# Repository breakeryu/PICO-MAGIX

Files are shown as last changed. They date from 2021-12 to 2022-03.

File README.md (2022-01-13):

# 1.PICO_MAGIX介绍
什么是PICO_MAGIX呢？
它是一款开源硬件，也是个使用Arduino的开源软件，后续会增加QT应用的一个开源代码仓库。

# 2.Hardware
硬件板卡使用了Altium Designer来设计。工程结构如下：

--hardware文件目录

* * *

--01_SCH        （存放工程的原理图文件）

--02_PCB        （存放工程的PCB文件）

--03_LIB         （存放工程的原理图库和PCB库文件）

--04_DATESHEET      （存放工程使用的数据手册）

--05-DOCUMENT     （存放工程导出的文件和bom等）

--06_PRODUCT        （存放工程的制版信息）

--PICO顶层工程          （使用AD软件打开的工程文件）

# 3.Software

软件使用Arduino IDE来进行编写，主要使用C和C++语言。

工程包括一个单元测试工程和项目发布工程。

目前正在编写单元测试工程。

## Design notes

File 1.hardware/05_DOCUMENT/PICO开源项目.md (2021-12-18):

PICO开源项目

# 一、环境构建

## 1.环境

现在使用PIO很难搞成功。使用arduino原生的IDE可以编译。接下来就用原生的IDE来编辑吧。

## 2.上传

问题中显示了部分上传的方式。

https://community.platformio.org/t/official-platformio-arduino-ide-support-for-the-raspberry-pi-pico-is-now-available/20792/9

## 3.项目开源地址

https://github.com/breakeryu/PICO-MAGIX

# 二、系统设计

## 1.子系统——环境传感器部分

环境传感器部分采用了几个部分：

AHT21B温湿度模块

VL6180X距离模块

st7735显示模块

MQ135气体检测模块

temt6000环境光模块

这样构成了一个环境的检测系统。

### 子系统功能：

该环境监测系统可以进行数据采集，显示。可以设置报警值。

使用QT设计一个上位机，可以使数据可视化，并且可以保存到本地。

## 2.车门/灯状态机系统

这一部分使用状态机测试的code，来模拟一个汽车车门和车灯控制器：

- 车门+车门灯

- 车内头氛围灯（开/关）+ 开关（单刀开关）

- 锁止机构（可以锁各个门，按下之后禁止开门）（单刀开关）

- 车钥匙开门（单刀开关）

- 车门开门（单刀开关）

### 子系统功能：

我们需要8个开关，然后是5个灯。

这样一个车门和灯配合的控制系统，在普通的汽车上面都是常见的。

现在我们使用LED和一些开关按键来模拟这个系统。

## 3.语音识别系统

使用启英泰伦的开源硬件。参考一个开源的灯项目，来集成到我的板卡上面。

# 三、硬件设计

硬件设计开源：在[开源仓库](https://github.com/breakeryu/PICO-MAGIX)中的[1.hardware](https://github.com/breakeryu/PICO-MAGIX/tree/master/1.hardware)部分。

硬件设计使用工具是AD19。原理图和PCB会生成PDF版本。

# 四、软件设计

# 六、项目依赖

使用Arduino平台，集成开发环境使用vscode和pio。

这里是我的主要代码参考文档：https://arduino-pico.readthedocs.io/en/latest/

使用的项目原来的git工程：https://github.com/earlephilhower/arduino-pico

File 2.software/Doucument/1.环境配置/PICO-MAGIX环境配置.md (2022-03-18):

PICO-MAGIX环境配置

# 一、开发环境

## 软件开发环境下载配置

现在使用Arduino IDE来进行开发。具体的使用工具有下面的几个工具：

### 1.Arduino IDE

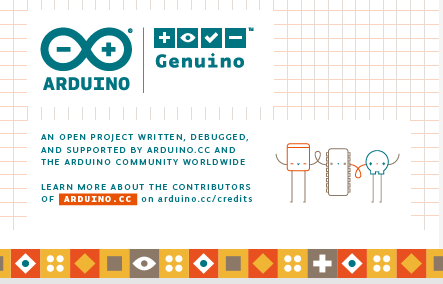
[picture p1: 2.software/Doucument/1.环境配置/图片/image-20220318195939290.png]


下载最新版。不要装在中文路径下面。安装JAVA等依赖。

我们主要使用Arduino IDE来进行工程编译，下载。

### 2.Vscode 

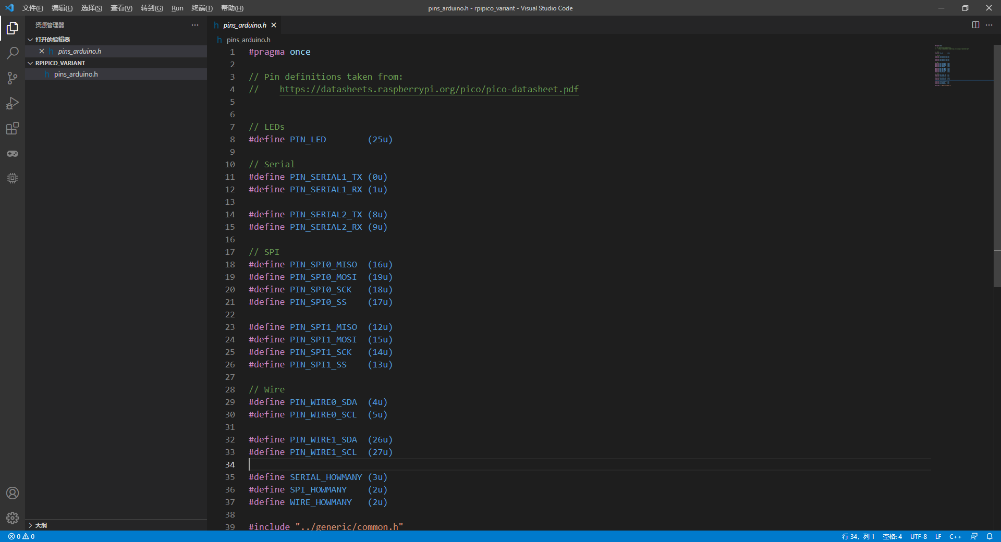
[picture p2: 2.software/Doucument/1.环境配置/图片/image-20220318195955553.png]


下载最新版。下载中文界面、C/C++插件等必要工具。

VScode用来进行编程。

## 环境配置的问题

### 1. vscode的输出中文乱码

如果你使用了VScode插件的版本的Arduino，碰到了编译出错的话，可以看下下面博客的解决办法。

这里为了没有这个错误，建议还是安装Arduino IDE，而不是从其他的地方安装插件。

参考了博客：https://blog.csdn.net/weixin_42225355/article/details/104906950

### 2.头文件包含问题

在VScode中我们只进行编写代码的工作，往往在vs里面会提示找不到相关头文件。

虽然现在没有什么好办法解决这个问题，但是他不影响后面我们编译、运行程序。VS对于我们来讲，他只是一个编写代码的工具。

### 3.文件夹创建方法

在写代码过程中，我们会将一类驱动放在一个文件夹中，使整个工程结构更加的清晰。

这里的说明在ArduinoIDE的环境中，创建相似的文件夹目录。

具体的方法：

- 首先创建文件夹src：这里我使用src文件夹做演示，在src中创建Led文件夹。

- 接着，我们把led.cpp和led.h放在src/Led文件夹中。

  ***注意***

  1.arduino ide使用c++后缀，里面代码可以完全使用c语言，也可以使用c++。但是要注意的是，新建的源文件一定要用cpp后缀。如果使用了c后缀，意思是一个c文件，ide会报错。

  2.文件夹的名字和Led和源文件的名字要有区别，不能完全一样，比如说上面的定义方法：文件夹名字：Led，源文件名：led.cpp。原因目前我还没有深入了解，这个可以给后续的同学研究。

- 在要使用的文件中引用这个文件夹中的头文件。

  使用#include “src/Led/led.h”来应用该文件。

在使用的时候例如下图中的是有工程文件夹，保存了一个src文件夹和其他的源文件：

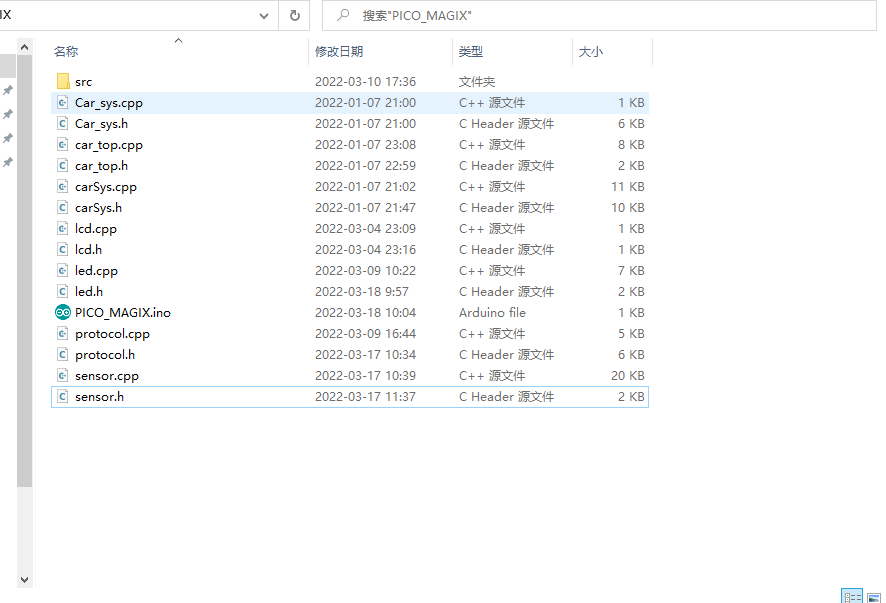
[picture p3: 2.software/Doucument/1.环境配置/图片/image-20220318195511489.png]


src中包含了两个自定义的库文件夹，分别是Modbus和vl6180。

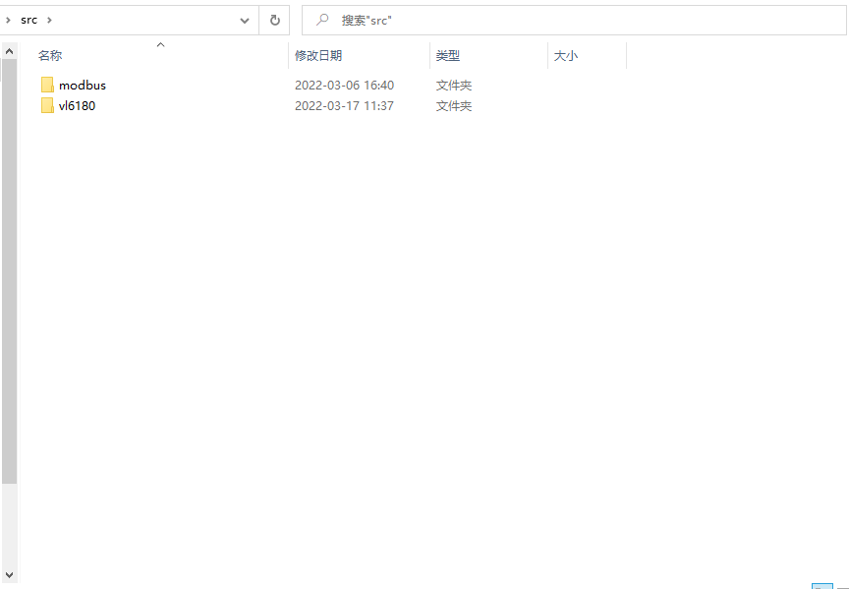
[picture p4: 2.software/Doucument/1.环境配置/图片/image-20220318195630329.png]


在modbus创建的源文件包括下面的部分。

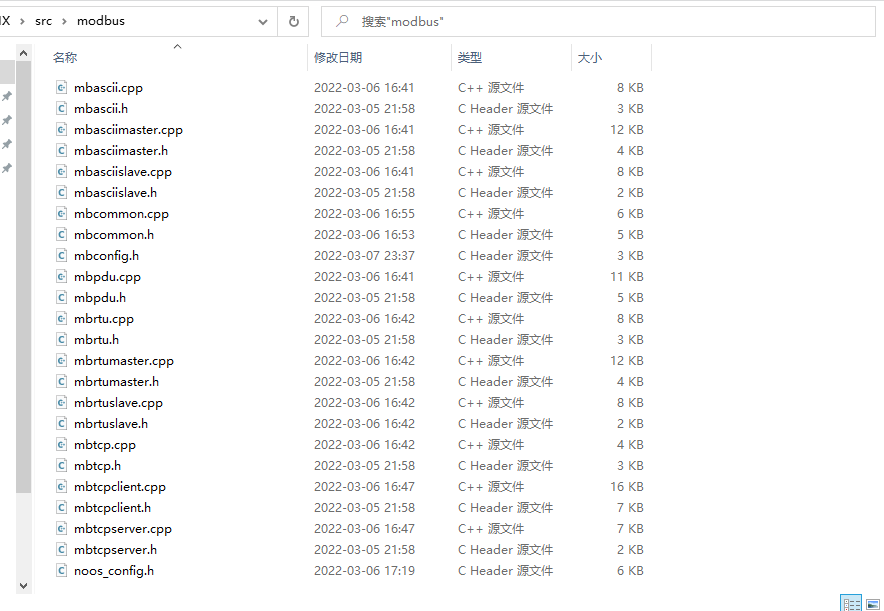
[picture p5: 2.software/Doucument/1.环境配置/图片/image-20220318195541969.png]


在modbus中最好不要再有其他的文件夹，那样会增加自己的工作量。

# 二、开发板环境配置

## Arduino IDE开发板配置

1. 打开 Arduino IDE ， 文件->首选项.

2. 在“附加开发板管理器网址”中新启一行，添加:

    https://github.com/earlephilhower/arduino-pico/releases/download/global/package_rp2040_index.json

3. 点击OK关闭对话框.

4. 点击Tools->Boards->Board Manager in the IDE

5. 搜索 “pico” ，select “Add”。

图文教程点击这里：https://arduino-pico.readthedocs.io/en/latest/install.html#installing-via-arduino-boards-manager

## VS CODE编写文件

1.用VS CODE打开工程文件夹

2.编写代码。

## 引用库文件

在software的文件夹中，lib文件夹中包括了我们使用到的library，这里使用到的库有三个：

> 1. Adafruit_NeoPixel
> 2. AHTxx
> 3. TFT_eSPI

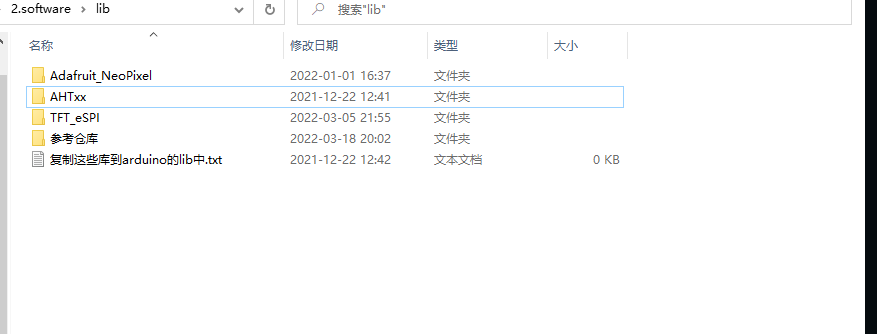
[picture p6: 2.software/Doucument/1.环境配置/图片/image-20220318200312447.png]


将这三个文件夹直接拷贝到arduino的安装路径下的libraries中，例如我的是e盘中的arduino：

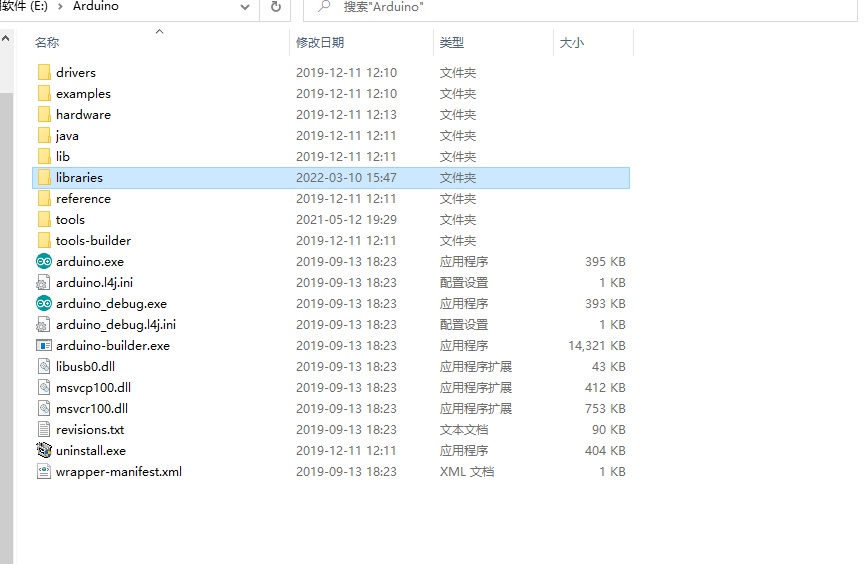
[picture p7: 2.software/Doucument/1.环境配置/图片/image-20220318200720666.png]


### LAST Reference

参考了博客来进行C++的库的编写：

https://www.cnblogs.com/lulipro/p/6090407.html

使用的板卡官方wiki：

https://arduino-pico.readthedocs.io/en/latest/

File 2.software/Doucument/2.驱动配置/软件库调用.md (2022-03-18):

软件库调用

# 1.TFT-eSPI

源仓库地址：https://github.com/Bodmer/TFT_eSPI

我对该仓库进行了修改，适应板子。大家一定要拷贝我给大家的库到你们的arduino路径中，不要直接下载源仓库。

# 2.AHTxx

源仓库地址：https://github.com/enjoyneering/AHTxx

我将这个仓库需要修改成板子能够使用的，接下来放到我的LIB里面。

另外参考的IIC库：

http://enmaking.com/article/ar_os1f1SJq

## 问题：7位的地址位！

以前一直我以为IIC的地址位是8位的，在Arduino的使用中也没有对该问题进行思考。

在今天看AHT20的数据手册和他的参考代码的时候，再回头看这个库，然后发现了这个问题。

对比51单片机和32的历程，这里面的IIC发送和接收都将地址移位加上W/R的位，arduino里面明显没有这个步骤。

在后面的IIC库里面，就有了这一步骤的说明：

**`address: 7bit i2c device address`**

使用Arduino的IIC库的时候，默认已经是将读/写考虑了进来，然后你只需要写入7位的地址位就可以。

# 3.WS2812驱动-Adafruit_NeoPixel

源仓库地址：https://github.com/adafruit/Adafruit_NeoPixel

这里是直接拷贝的源仓库代码。

# 4.MODBUS参考驱动

源仓库地址：木南创智https://github.com/foxclever/Modbus

非常感谢木南团队的贡献，我参考了他们的驱动，很容易就构建出来的自己的MODBUS从机设备。

在我的仓库里面没有下载这个驱动，但是工程中有这里面的驱动源代码。建议大家可以下载该驱动来进行自己的参考设计。

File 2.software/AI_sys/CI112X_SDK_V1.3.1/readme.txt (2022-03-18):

发布版本：CI112X_SDK_V1.3.1

更新内容：

1、更新asr库
（1）、优化解码算力，更新解码库
（2）、增加内存不足（"not enough mem xx"），算力不足提示打印("not enough cpu xx")
（3）、增加默认逐帧配置(针对1102/1103)
（4）、去除冗余打印
2、解决1代串口协议语音关闭后无法通过串口协议打开的bug
3、升级工具更新到版本 V3.4.5

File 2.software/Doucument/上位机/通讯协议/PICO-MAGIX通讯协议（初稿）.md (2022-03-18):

PICO-MAGIX通讯协议（初稿）

# 第一章：综述

PICO_MAGIX通讯协议文件是总括上位机和下位机定义的通讯方式，所有的通讯指令都在本文件中包括。

- 本协议参考MODBUS协议进行编写。

- 本协议软件参考木南协议进行编写。

https://github.com/foxclever/Modbus

- 本协议参考GESHE测控大师软件编写。

http://www.geshe.com/zh-cn/

- 本协议参考“中国电光MODBUS3.0 馈电开关”编写。

# 第二章：通讯协议总括

本章将总括使用的ModBus-RTU通讯协议。

# 各指令对应的地址说明

## 1.读单个线圈01命令（起始地址：00H）

| 线圈起始地址 | 位功能定义 | 事件代码（HEX） |
| :---: | :---: | :---: |
| 00H | 设备停止状态 | —— |
| 01H | 设备运行状态 | —— |
| 02H | 备用 | —— |
| 03H | 备用 | —— |
| 04H | 备用 | —— |
| 05H | 备用 | —— |
| 06H | 备用 | —— |
| 07H | 备用 | —— |
| 08H | 备用 | —— |
| 09H | 备用 | —— |
| 0AH | 备用 | —— |
| 0BH | 备用 | —— |
| 0CH | 备用 | —— |
| 0DH | 备用 | —— |
| 0FH | 备用 | —— |
| 10H | 灯带运行状态（启动：1，停止：0） | |
| 11H | 灯带剧场模式（开启：1，关闭：0） | |
| 12H | 灯带彩虹模式（开启：1，关闭：0） | |
| 13H | 灯带测试模式（开启：1，关闭：0） | |
| | | |
| | | |
| | | |
| | | |
| | | |
| | | |
| | | |
| | | |
| | | |
| | | |

## 2.写单个线圈05命令（起始地址：100H）

| 线圈起始地址 | 位功能定义 | 事件代码（HEX） |
| :---: | :---: | :---: |
| 100H | 灯带运行（启动：1，停止：0） | —— |
| 101H | 灯带剧场打开（开启：1，关闭：0） | —— |
| 102H | 灯带彩虹打开（开启：1，关闭：0） | —— |
| 103H | 灯带测试打开（开启：1，关闭：0） | —— |
| 104H | 读AL6180读写寄存器 | —— |
| 105H | 写AL6180读写寄存器 | —— |
| 106H | 读AL6180结果寄存器 | —— |
| 107H | | —— |
| 108H | | —— |
| 109H | | —— |
| 0AH | | —— |
| 0BH | | —— |
| 0CH | | —— |
| 0DH | | —— |
| 0FH | | —— |
| 10H | | |
| 11H | | |
| 12H | | |
| 13H | | |
| | | |
| | | |
| | | |
| | | |
| | | |
| | | |
| | | |
| | | |
| | | |
| | | |

## 3.读多路寄存器03命令（起始地址：00H）——模拟量

| 寄存器起始地址 | 功能定义 | 系数 |
| :---: | :---: | :--: |
| 00H | 备用 |  ——  |
| 01H | 备用 |  ——  |
| 02H | 备用 |  ——  |
| 03H | 备用 |  ——  |
| 04H | 备用 |  ——  |
| 05H | 备用 |  ——  |
| 06H | 备用 |  ——  |
| 07H | 备用 |  ——  |
| 08H | 备用 |  ——  |
| 09H | 备用 |  ——  |
| 0AH | 系统电压 | 0.01 |
| 0BH | 气体浓度 |  1 |
| 0CH | 光强 |  1 |
| 0DH | 温度 | 0.01 |
| 0EH | 湿度 | 0.01 |
| 0FH | 距离 |  1 |
| 10H | | |
| 11H | | |
| 12H | | |
| 13H | | |
| | | |
| | | |
| | | |
| | | |
| | | |
| | | |
| | | |
| | | |
| | | |
| | | |

## 4.读多路寄存器03命令（起始地址：30H）——定制参数

| 序号 | 寄存器起始地址 | 功能定义 | 备注 |
| ---- | --- | --- | --- |
| 1 | 30H | Model_id | 实际8位无符号，复位后为0xb4 |
| 2 | 31H | Model_Rev_Major | 实际8位无符号，复位后为0x1，值有效范围0~7 |
| 3 | 32H | Model_Rev_Minor | 实际8位无符号，复位后为0x3，值有效范围0~7 |
| 4 | 33H | Module_Rev_Major | 实际8位无符号，复位后为0x1，值有效范围0~7 |
| 5 | 34H | Module_Rev_Minor | 实际8位无符号，复位后为0x2，值有效范围0~7 |
| 6 | 35H | Date_Hi | 实际8位无符号，高4位为年，低4位为月 |
| 7 | 36H | Date_Lo | 实际8位无符号，高4位为日，低4位为脉冲数 |
| 8 | 37H | Id_Time | 实际16位无符号，时间 = 寄存器值 *2 |
| 9 | 38H | Mode_GPIO0 | 实际8位无符号，复位后为0x60 |
| 10 | 39H | Mode_GPIO1 | 实际8位无符号，复位后为0x20 |
| 11 | 3AH | History_Ctrl | 实际8位无符号，复位后为0x0 |
| 12 | 3BH | Interrupt_Config_GPIO | 实际8位无符号，复位后为0x0 |
| 13 | 3CH | Interrupt_Clear | 实际8位无符号，复位后为0x0 |
| 14 | 3DH | Fresh_Out_Of_Reset | 实际8位无符号，复位后为0x1 |
| 15 | 3EH | Grouped_Para_Hold | 实际8位无符号，复位后为0x0 |
| 16 | 3FH | Range_start | 实际8位无符号，复位后为0x0 |
| 17 | 40H | Range_Thresh_High | 实际8位无符号，复位后为0xFF |
| 18 | 41H | Range_Thresh_Low | 实际8位无符号，复位后为0x0 |
| 19 | 42H | Range_InterMeasurement_Period | 实际8位无符号，复位后为0xFF |
| 20 | 43H | Range_Max_ConverGence_Time | 实际8位无符号，复位后为0x31 |
| 21 | 44H | Range_CrossTalk_Compensation_Rate | 实际16位无符号，复位后为0x0 |
| 22 | 45H | Range_CrossTalk_Valid_Height | 实际8位无符号，复位后为0x14 |
| 23 | 46H | Range_Early_ConverGence_Estimate  | 实际16位无符号，复位后为0x0 |
| 24 | 47H | Range_Part_To_Part_Range_Offset | 实际8位无符号，复位后为0xYY |
| 25 | 48H | Range_Ignore_Valid_Height | 实际8位无符号，复位后为0x0 |
| 26 | 49H | Range_Ingore_Threshold | 实际16位无符号，复位后为0x0 |
| 27 | 4AH | Range_Max_Ambient_Level_Mult | 实际8位无符号，复位后为0xA0 |
| 28 | 4BH | Range_Check_Enables | 实际8位无符号，复位后为0x11 |
| 29 | 4CH | Range_Vhv_RecalibRate | 实际8位无符号，复位后为0x0 |
| 30 | 4DH | Range_Vhv_Repeat_Rate | 实际8位无符号，复位后为0x0 |
| 31 | 4EH | Als_Start | 实际8位无符号，复位后为0x0 |
| 32 | 4FH | Als_Thresh_High | 实际16位无符号，复位后为0xFFFF |
| 33 | 50H | Als_Thresh_Low | 实际16位无符号，复位后为0x0 |
| 34 | 51H | Als_InterMeasurement_Period | 实际8位无符号，复位后为0xFF |
| 35 | 52H | Als_Analogue_Gain | 实际8位无符号，复位后为0x06 |
| 36 | 53H | Als_interRation_Period | 实际16位无符号，复位后为0x0 |
| 37 | 54H | Readout_Averaging_Sample_Period | 实际8位无符号，复位后为0x30 |
| 38 | 55H | Firmware_bootup | 实际8位无符号，复位后为0x1 |
| 39 | 56H | Firmaware_Result_Scaler | 实际8位无符号，复位后为0x1 |
| 40 | 57H | I2C_Slave_Device_Adderss | 实际8位无符号，复位后为0x29 |
| 41 | 58H | InterLeaved_Mode_Enable | 实际8位无符号，复位后为0x0 |
| 1 | 59H | Range_Status | 实际8位无符号，复位后为0x01 |
| 2 | 5AH | Als_Status | 实际8位无符号，复位后为0x01 |
| 3 | 5BH | Interrupt_Status_GPIO | 实际8位无符号，复位后为0x00 |
| 4 | 5CH | Als_Value | 实际16位无符号，复位后为0x00 |
| 5 | 5DH | History_Buffer0 | 实际16位无符号，复位后为0x00 |
| 6 | 5EH | History_Buffer1 | 实际16位无符号，复位后为0x00 |
| 7 | 5FH | History_Buffer2 | 实际16位无符号，复位后为0x00 |
| 8 | 60H | History_Buffer3 | 实际16位无符号，复位后为0x00 |
| 9 | 61H | History_Buffer4 | 实际16位无符号，复位后为0x00 |
| 10 | 62H | History_Buffer5 | 实际16位无符号，复位后为0x00 |
| 11 | 63H | History_Buffer6 | 实际16位无符号，复位后为0x00 |
| 12 | 64H | History_Buffer7 | 实际16位无符号，复位后为0x00 |
| 13 | 65H | Range_Value | 实际8位无符号，复位后为0x00 |
| 14 | 66H | Range_Raw | 实际8位无符号，复位后为0x00 |
| 15 | 67H | Range_Rerurn_Rate | 实际16位无符号，复位后为0x00 |
| 16 | 68H | Range_Reference_Rate | 实际16位无符号，复位后为0x00 |
| 17 | 69H | Range_Return_Signal_Count_H | 实际32位无符号，复位后为0x00 |
| 18 | 6AH | Range_Return_Signal_Count_L | 实际32位无符号，复位后为0x00 |
| 19 | 6BH | Range_Reference_Signal_Count_H | 实际32位无符号，复位后为0x00 |
| 20 | 6CH | Range_Reference_Signal_Count_L | 实际32位无符号，复位后为0x00 |
| 21 | 6DH | Range_Return_Amb_Count_H | 实际32位无符号，复位后为0x00 |
| 22 | 6EH | Range_Return_Amb_Count_L | 实际32位无符号，复位后为0x00 |
| 23 | 6FH | Range_Reference_Amb_Count_H | 实际32位无符号，复位后为0x00 |
| 24 | 70H | Range_Reference_Amb_Count_L | 实际32位无符号，复位后为0x00 |
| 25 | 71H | Range_Return_Conv_Time_H | 实际32位无符号，复位后为0x00 |
| 26 | 72H | Range_Return_Conv_Time_L | 实际32位无符号，复位后为0x00 |
| 27 | 73H | Range_Reference_Conv_Time_H | 实际32位无符号，复位后为0x00 |
| 28 | 74H | Range_Reference_Conv_Time_L | 实际32位无符号，复位后为0x00 |

## 5.写单路寄存器06命令、写多路寄存器10命令（起始地址：30H）——定制参数

| 序号 | 寄存器起始地址 | 功能定义 | 备注 |
| ---- | --- | --- | --- |
| 1 | 30H | Model_id | 实际8位无符号，复位后为0xb4 |
| 2 | 31H | Model_Rev_Major | 实际8位无符号，复位后为0x1，值有效范围0~7 |
| 3 | 32H | Model_Rev_Minor | 实际8位无符号，复位后为0x3，值有效范围0~7 |
| 4 | 33H | Module_Rev_Major | 实际8位无符号，复位后为0x1，值有效范围0~7 |
| 5 | 34H | Module_Rev_Minor | 实际8位无符号，复位后为0x2，值有效范围0~7 |
| 6 | 35H | Date_Hi | 实际8位无符号，高4位为年，低4位为月 |
| 7 | 36H | Date_Lo | 实际8位无符号，高4位为日，低4位为脉冲数 |
| 8 | 37H | Id_Time | 实际16位无符号，时间 = 寄存器值 *2 |
| 9 | 38H | Mode_GPIO0 | 实际8位无符号，复位后为0x60 |
| 10 | 39H | Mode_GPIO1 | 实际8位无符号，复位后为0x20 |
| 11 | 3AH | History_Ctrl | 实际8位无符号，复位后为0x0 |
| 12 | 3BH | Interrupt_Config_GPIO | 实际8位无符号，复位后为0x0 |
| 13 | 3CH | Interrupt_Clear | 实际8位无符号，复位后为0x0 |
| 14 | 3DH | Fresh_Out_Of_Reset | 实际8位无符号，复位后为0x1 |
| 15 | 3EH | Grouped_Para_Hold | 实际8位无符号，复位后为0x0 |
| 16 | 3FH | Range_start | 实际8位无符号，复位后为0x0 |
| 17 | 40H | Range_Thresh_High | 实际8位无符号，复位后为0xFF |
| 18 | 41H | Range_Thresh_Low | 实际8位无符号，复位后为0x0 |
| 19 | 42H | Range_InterMeasurement_Period | 实际8位无符号，复位后为0xFF |
| 20 | 43H | Range_Max_ConverGence_Time | 实际8位无符号，复位后为0x31 |
| 21 | 44H | Range_CrossTalk_Compensation_Rate | 实际16位无符号，复位后为0x0 |
| 22 | 45H | Range_CrossTalk_Valid_Height | 实际8位无符号，复位后为0x14 |
| 23 | 46H | Range_Early_ConverGence_Estimate  | 实际16位无符号，复位后为0x0 |
| 24 | 47H | Range_Part_To_Part_Range_Offset | 实际8位无符号，复位后为0xYY |
| 25 | 48H | Range_Ignore_Valid_Height | 实际8位无符号，复位后为0x0 |
| 26 | 49H | Range_Ingore_Threshold | 实际16位无符号，复位后为0x0 |
| 27 | 4AH | Range_Max_Ambient_Level_Mult | 实际8位无符号，复位后为0xA0 |
| 28 | 4BH | Range_Check_Enables | 实际8位无符号，复位后为0x11 |
| 29 | 4CH | Range_Vhv_RecalibRate | 实际8位无符号，复位后为0x0 |
| 30 | 4DH | Range_Vhv_Repeat_Rate | 实际8位无符号，复位后为0x0 |
| 31 | 4EH | Als_Start | 实际8位无符号，复位后为0x0 |
| 32 | 4FH | Als_Thresh_High | 实际16位无符号，复位后为0xFFFF |
| 33 | 50H | Als_Thresh_Low | 实际16位无符号，复位后为0x0 |
| 34 | 51H | Als_InterMeasurement_Period | 实际8位无符号，复位后为0xFF |
| 35 | 52H | Als_Analogue_Gain | 实际8位无符号，复位后为0x06 |
| 36 | 53H | Als_interRation_Period | 实际16位无符号，复位后为0x0 |
| 37 | 54H | Readout_Averaging_Sample_Period | 实际8位无符号，复位后为0x30 |
| 38 | 55H | Firmware_bootup | 实际8位无符号，复位后为0x1 |
| 39 | 56H | Firmaware_Result_Scaler | 实际8位无符号，复位后为0x1 |
| 40 | 57H | I2C_Slave_Device_Adderss | 实际8位无符号，复位后为0x29 |
| 41 | 58H | InterLeaved_Mode_Enable | 实际8位无符号，复位后为0x0 |

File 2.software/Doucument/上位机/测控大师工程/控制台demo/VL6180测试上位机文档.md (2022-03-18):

VL6180测试上位机文档

## 1.寄存器参数读取对照

| 序号 | 寄存器名 | 数据类型 | R/W  | Modbus地址 | 软件变量名 |
| :--: | :---: | :---: | :--: | --- | --- |
|  1 | **IDENTIFICATION__MODEL_ID** | Byte | R/W  | 30H | Model_id |
|  2 | **IDENTIFICATION__MODEL_REV_MAJOR** | Byte | R/W  | 31H | Model_Rev_Major |
|  3 | **IDENTIFICATION__MODEL_REV_MINOR** | Byte | R/W  | 32H | Model_Rev_Minor |
|  4 | **IDENTIFICATION__MODULE_REV_MAJOR** | Byte | R/W  | 33H | Module_Rev_Major |
|  5 | **IDENTIFICATION__MODULE_REV_MINOR** | Byte | R/W  | 34H | Module_Rev_Minor |
|  6 | **IDENTIFICATION__DATE_HI** | Byte | R/W  | 35H | Date_Hi |
|  7 | **IDENTIFICATION__DATE_LO** | Byte | R/W  | 36H | Date_Lo |
|  8 | **IDENTIFICATION__TIME** |  UInt16  | R/W  | 37H | Id_Time |
|  9 | **SYSTEM__MODE_GPIO0** | Byte | R/W  | 38H | Mode_GPIO0 |
|  10  | **SYSTEM__MODE_GPIO1** | Byte | R/W  | 39H | Mode_GPIO1 |
|  11  | **SYSTEM__HISTORY_CTRL** | Byte | R/W  | 3AH | History_Ctrl |
|  12  | **SYSTEM__INTERRUPT_CONFIG_GPIO** | Byte | R/W  | 3BH | Interrupt_Config_GPIO |
|  13  | **SYSTEM__INTERRUPT_CLEAR** | Byte | R/W  | 3CH | Interrupt_Clear |
|  14  | **SYSTEM__FRESH_OUT_OF_RESET** | Byte | R/W  | 3DH | Fresh_Out_Of_Reset |
|  15  | **SYSTEM__GROUPED_PARAMETER_HOLD** | Byte | R/W  | 3EH | Grouped_Para_Hold |
|  16  | **SYSRANGE__START** | Byte | R/W  | 3FH | Range_start |
|  17  | **SYSRANGE__THRESH_HIGH** | Byte | R/W  | 40H | Range_Thresh_High |
|  18  | **SYSRANGE__THRESH_LOW** | Byte | R/W  | 41H | Range_Thresh_Low |
|  19  | **SYSRANGE__INTERMEASUREMENT_PERIOD** | Byte | R/W  | 42H | Range_InterMeasurement_Period |
|  20  | **SYSRANGE__MAX_CONVERGENCE_TIME** | Byte | R/W  | 43H | Range_Max_ConverGence_Time |
|  21  | **SYSRANGE__CROSSTALK_COMPENSATION_RATE** |  UInt16  | R/W  | 44H | Range_CrossTalk_Compensation_Rate |
|  22  | **SYSRANGE__CROSSTALK_VALID_HEIGHT** | Byte | R/W  | 45H | Range_CrossTalk_Valid_Height |
|  23  | **SYSRANGE__EARLY_CONVERGENCE_ESTIMATE**  |  UInt16  | R/W  | 46H | Range_Early_ConverGence_Estimate  |
|  24  |  **SYSRANGE__PART_TO_PART_RANGE_OFFSET**  | Byte | R/W  | 47H | Range_Part_To_Part_Range_Offset |
|  25  |  **SYSRANGE__RANGE_IGNORE_VALID_HEIGHT**  | Byte | R/W  | 48H | Range_Ignore_Valid_Height |
|  26  | **SYSRANGE__RANGE_IGNORE_THRESHOLD** |  UInt16  | R/W  | 49H | Range_Ingore_Threshold |
|  27  | **SYSRANGE__MAX_AMBIENT_LEVEL_MULT** | Byte | R/W  | 4AH | Range_Max_Ambient_Level_Mult |
|  28  | **SYSRANGE__RANGE_CHECK_ENABLES** | Byte | R/W  | 4BH | Range_Check_Enables |
|  29  | **SYSRANGE__VHV_RECALIBRATE** | Byte | R/W  | 4CH | Range_Vhv_RecalibRate |
|  30  | **SYSRANGE__VHV_REPEAT_RATE** | Byte | R/W  | 4DH | Range_Vhv_Repeat_Rate |
|  31  | **SYSALS__START** | Byte | R/W  | 4EH | Als_Start |
|  32  | **SYSALS__THRESH_HIGH** |  UInt16  | R/W  | 4FH | Als_Thresh_High |
|  33  | **SYSALS__THRESH_LOW** |  UInt16  | R/W  | 50H | Als_Thresh_Low |
|  34  | **SYSALS__INTERMEASUREMENT_PERIOD** | Byte | R/W  | 51H | Als_InterMeasurement_Period |
|  35  | **SYSALS__ANALOGUE_GAIN** | Byte | R/W  | 52H | Als_Analogue_Gain |
|  36  | **SYSALS__INTEGRATION_PERIOD** |  UInt16  | R/W  | 53H | Als_interRation_Period |
|  37  | **RESULT__RANGE_STATUS** | Byte |  R | 59H | Range_Status |
|  38  | **RESULT__ALS_STATUS** | Byte |  R | 5AH | Als_Status |
|  39  | **RESULT__INTERRUPT_STATUS_GPIO** | Byte |  R | 5BH | Interrupt_Status_GPIO |
|  40  | **RESULT__ALS_VAL** |  UInt16  |  R | 5CH | Als_Value |
|  41  | **RESULT__HISTORY_BUFFER_0** |  UInt16  |  R | 5DH | History_Buffer0 |
|  42  | **RESULT__HISTORY_BUFFER_1** |  UInt16  |  R | 5EH | History_Buffer1 |
|  43  | **RESULT__HISTORY_BUFFER_2** |  UInt16  |  R | 5FH | History_Buffer2 |
|  44  | **RESULT__HISTORY_BUFFER_3** |  UInt16  |  R | 60H | History_Buffer3 |
|  45  | **RESULT__HISTORY_BUFFER_4** |  UInt16  |  R | 61H | History_Buffer4 |
|  46  | **RESULT__HISTORY_BUFFER_5** |  UInt16  |  R | 62H | History_Buffer5 |
|  47  | **RESULT__HISTORY_BUFFER_6** |  UInt16  |  R | 63H | History_Buffer6 |
|  48  | **RESULT__HISTORY_BUFFER_7** |  UInt16  |  R | 64H | History_Buffer7 |
|  49  | **RESULT__RANGE_VAL** | Byte |  R | 65H | Range_Value |
|  50  | **RESULT__RANGE_RAW** | Byte |  R | 66H | Range_Raw |
|  51  | **RESULT__RANGE_RETURN_RATE** |  UInt16  |  R | 67H | Range_Rerurn_Rate |
|  52  | **RESULT__RANGE_REFERENCE_RATE** |  UInt16  |  R | 68H | Range_Reference_Rate |
|  53  | **RESULT__RANGE_RETURN_SIGNAL_COUNT** |  UInt32  |  R | 69H\|6AH | Range_Return_Signal_Count |
|  54  | **RESULT__RANGE_REFERENCE_SIGNAL_COUNT**  |  UInt32  |  R | 6BH\|6CH | Range_Reference_Signal_Count |
|  55  | **RESULT__RANGE_RETURN_AMB_COUNT** |  UInt32  |  R | 6DH\|6EH | Range_Return_Amb_Count |
|  56  | **RESULT__RANGE_REFERENCE_AMB_COUNT** |  UInt32  |  R | 6FH\|70H | Range_Reference_Amb_Count |
|  57  | **RESULT__RANGE_RETURN_CONV_TIME** |  UInt32  |  R | 71H\|72H | Range_Return_Conv_Time |
|  58  | **RESULT__RANGE_REFERENCE_CONV_TIME** |  UInt32  |  R | 73H\|74H | Range_Reference_Conv_Time |
|  59  | **READOUT__AVERAGING_SAMPLE_PERIOD** | Byte | R/W  | 54H | Readout_Averaging_Sample_Period |
|  60  | **FIRMWARE__BOOTUP** | Byte | R/W  | 55H | Firmware_bootup |
|  61  | **FIRMWARE__RESULT_SCALER** | Byte | R/W  | 56H | Firmaware_Result_Scaler |
|  62  | **I2C_SLAVE__DEVICE_ADDRESS** | Byte | R/W  | 57H | I2C_Slave_Device_Adderss |
|  63  | **INTERLEAVED_MODE__ENABLE** | Byte | R/W  | 58H | InterLeaved_Mode_Enable |

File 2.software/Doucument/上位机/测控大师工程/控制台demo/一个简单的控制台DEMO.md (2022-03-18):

一个简单的控制台DEMO

# 一、DEMO说明

我们从这个教程中能够练习以下几个格西测控大师的使用方法：

1. 简单控件使用
2. 事件脚本的编写
3. 自定义序列命令
4. 串口设备的使用

# 二、开始吧

## 1.创建一个画面

在画面中，使用了自定义的画布，使用了按键和开关控件。

## 2.创建一个设备和接口

这里的命名为默认名字,串口。

# 三、在脚本中执行步骤的几种方式

## 1.使用步骤的ID名

`Context.StartStep("82BCBA44-AD16-4214-BA0F-AD6D7E3BFC9A");`

## 2.使用步骤所处的序列位置

`Context.StartStep("控制台测试序列/写LED系统状态1");`

## 3.使用变量

`Context.StartStep(Context.Variants["步骤名/LED写1"].ToString());`

# 四、数据绑定

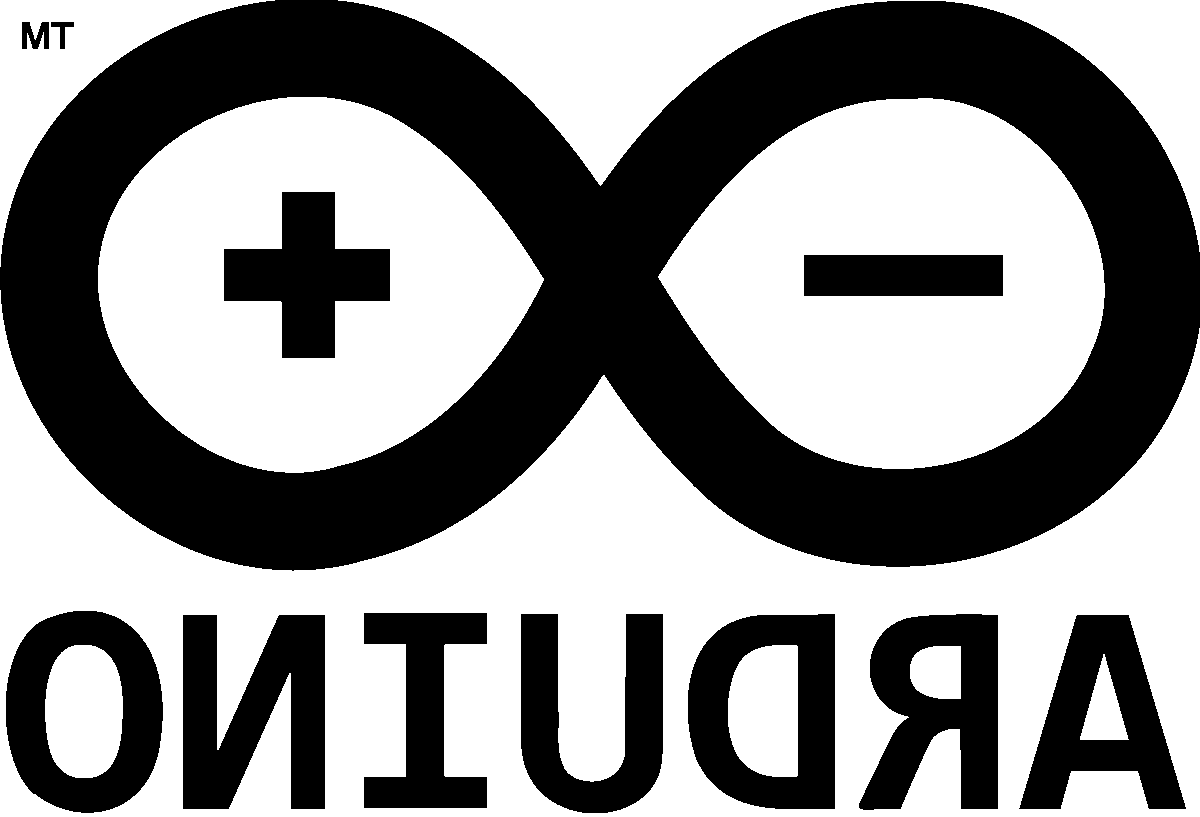
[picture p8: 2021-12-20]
1.hardware/05_DOCUMENT/arduino.bmp

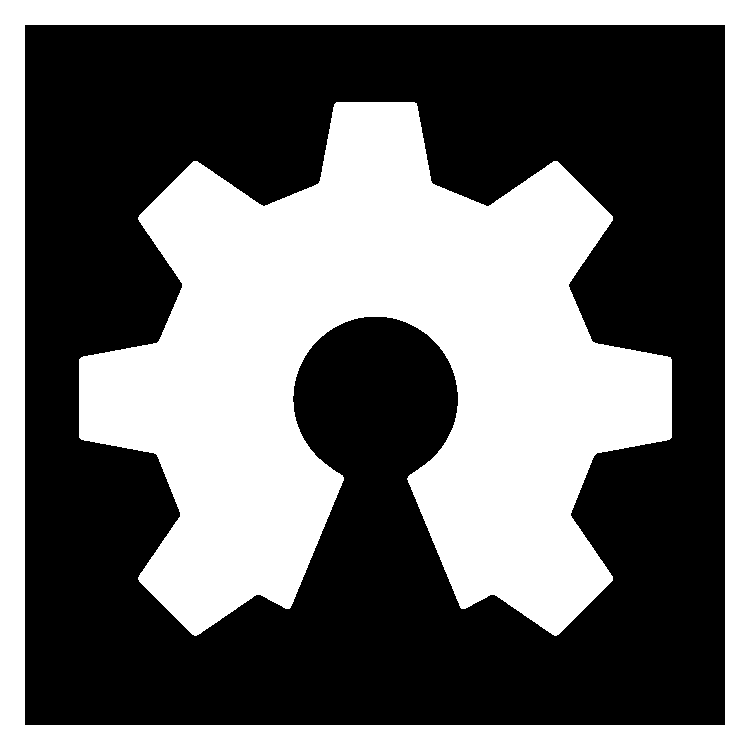
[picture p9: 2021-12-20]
1.hardware/05_DOCUMENT/opensource.bmp

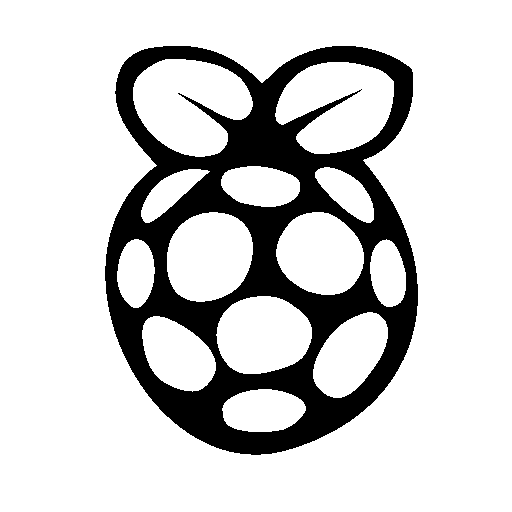
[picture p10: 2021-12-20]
1.hardware/05_DOCUMENT/PI.bmp

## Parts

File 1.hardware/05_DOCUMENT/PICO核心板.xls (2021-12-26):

Comment | Description | Designator | Footprint | LibRef | Quantity
TSA343G00-250J2 |  | BOOTSEL1, RESET1 | SW-SMD_4P-L6.2-W6.3-P4.00-LS9.4 | TSA343G00-250J2 | 2
T_Cap_0603_0.1uF_25V_X5R | 贴片电容 | C1, C5, C21, C23, C24, C27, C28, C30, C32, C33, C34, C35, C36, C37, C38, C39, C40, C41, C42 | 0402_C | T_Cap_0603_0.1uF_25V_X5R | 19
T_Cap_1206_47uF_10V_X5R | 贴片电容 | C2 | 0402_C | T_Cap_1206_47uF_10V_X5R | 1
T_Cap_1206_47uF_10V_X5R | 贴片电容 | C3 | 1206_C | T_Cap_1206_47uF_10V_X5R | 1
T_Cap_0603_10uF_16V_X5R | 贴片电容 | C4, C20, C22 | 0402_C | T_Cap_0603_10uF_16V_X5R | 3
4.7nF |  | C6 | 0402_C | Cap | 1
T_Cap_0603_10nF_50V_X7R | 贴片电容 | C7 | 0402_C | T_Cap_0603_10nF_50V_X7R | 1
39pF |  | C8 | 0402_C | Cap | 1
0.1u |  | C9, C10, C12, C13, C14, C15, C16, C17, C18 | 0402_C | 0.1u | 9
1u |  | C11, C19 | 0402_C | 0.1u | 2
15p |  | C25, C26 | 0402_C | 15p | 2
10n |  | C29 | 0402_C | 10n | 1
1n |  | C31 | 0402_C | 1n | 1
spker |  | C43 | XH2.54A-2 | SPK | 1
3.5*1.3 | 低压电源接口 | CON1 | DC-IN-TH_DC-005-5A-2.5 | P-DC | 1
T_SS34 | 肖特基二极管 | D1 | SMA_L4.3-W2.6-LS5.2-RD | T_SS34 | 1
T_LED_Red_0805 | 红色LED灯 | D2, D3, D4 | 0603_LED | T_LED_Red_0805 | 3
1N4007W |  | D5 | SMA_L4.3-W2.6-LS5.2-RD | 1N4007W | 1
WS2812 |  | D6, D7, D8, D9, D10, D11, D12, D13, D14, D15, D16, D17, D18, D19, D20, D21 | LED-SMD_4P-L3.5-W3.5-TL_WS2812B | WS2812 | 16
st7735 |  | D22 | HDR1X8 | st7735 | 1
T_LED_Red_0805 | 红色LED灯 | D23, D24, D25, D26, D27 | LED-TH_L5.0-W2.7-FD | T_LED_Red_0805 | 5
16V 2A |  | F1 | 1206_FUSE | Fuse | 1
HDR-F-2.54_1x3 |  | H1, H2 | XH2.54A-3 | HDR-F-2.54_1x3 | 2
TSA343G00-250J2 |  | key1, key2, key3, key4, key5, key6, key7, key8 | SW-TH_DEALON_MS-12D19-G2 | TSA343G00-250J2 | 8
6.8uH |  | L1 | IND-SMD_L5.8-W5.2 | Inductor | 1
RGB-3528 | 三基色LED | LED1, LED2, LED3 | LED-TH_4P-BD6.9-P1.27-R | LED-RGB-3528 | 3
咪头 |  | m1 | MIC-TH_BD6.0-P1.90-D0.4-L-RD | mic | 1
Header 2H | Header, 2-Pin, Right Angle | P1 | XH2.54A-2 | Header 2H | 1
T_Res_0603_10k_1%_1/10W | 贴片电阻 | R1, R4, R5 | 0402_R | T_Res_0603_10k_1%_1/10W | 3
49.9k |  | R2 | 0402_R | Res | 1
1.91k |  | R3 | 0402_R | Res | 1
T_Res_0603_4.3k_5%_1/10W | 贴片电阻 | R6, R27, R28, R29, R30, R31, R32, R33, R34, R35, R36, R37, R38, R39 | 0402_R | T_Res_0603_4.3k_5%_1/10W | 14
27 |  | R7, R8 | 0402_R | 27 | 2
DNF（不装） |  | R9 | 0402_R | DNF（不装） | 1
1k |  | R10, R11, R12, R13, R17, R18, R19, R21, R22 | 0402_R | 1k | 9
10k |  | R14, R20 | 0402_R | 1k | 2
200k |  | R15 | 0402_R | 200k | 1
100k |  | R16 | 0402_R | 100k | 1
100r |  | R23, R25, R26 | 0402_R | 100k | 3
4.7k |  | R24 | 0402_R | 100k | 1
W25Q16JVSSIQ |  | ROM1 | SOIC8-208mil | W25Q16JVSSIQ | 1
SS-12F23 | 1路波动开关 | S1, S2 | SW-TH_MT-0-103-A101-M200-RS | SSW-1P | 2
PICO |  | U1 | LQFN-56_L7.0-W7.0-P0.4-EP | PICO_CORE | 1
TPS54331DR | TI, 3A, 3.5-28V, Buck | U2 | SOIC8E | TPS54331 | 1
T_AMS1117-3.3V | 电源芯片 | U3 | SOT223 | T_AMS1117-3.3V | 1
CH340E |  | U4 | MSOP-10_L3.0-W3.0-P0.50-LS5.0-BL | CH340E | 1
气体传感器 |  | U5 | XH2.54A-4 | MQ135 | 1
AHT21B |  | U6 | XH2.54A-4 | AHT21B | 1
VL6180X |  | U7 | XH2.54A-4 | VL6180X | 1
TEMT6000 |  | U8 | XH2.54A-3 | TEMT6000 | 1
CI-C22GS02S |  | U9 | SMD-17_L20.0-W1.80-CI-C22GS02S | CI-C22GS02S | 1
TYPEC-302-BRP16SC08 |  | USB1 | USB-C-SMD_TYPEC-302-BRP16SC08 | TYPEC-302-BRP16SC08 | 1
MICROUSB FEMALE |  | USB2 | USB-B/S_A | MICROUSB FEMALE | 1
12MHz |  | X1 | OSC 3225-4P | 12MHz | 1

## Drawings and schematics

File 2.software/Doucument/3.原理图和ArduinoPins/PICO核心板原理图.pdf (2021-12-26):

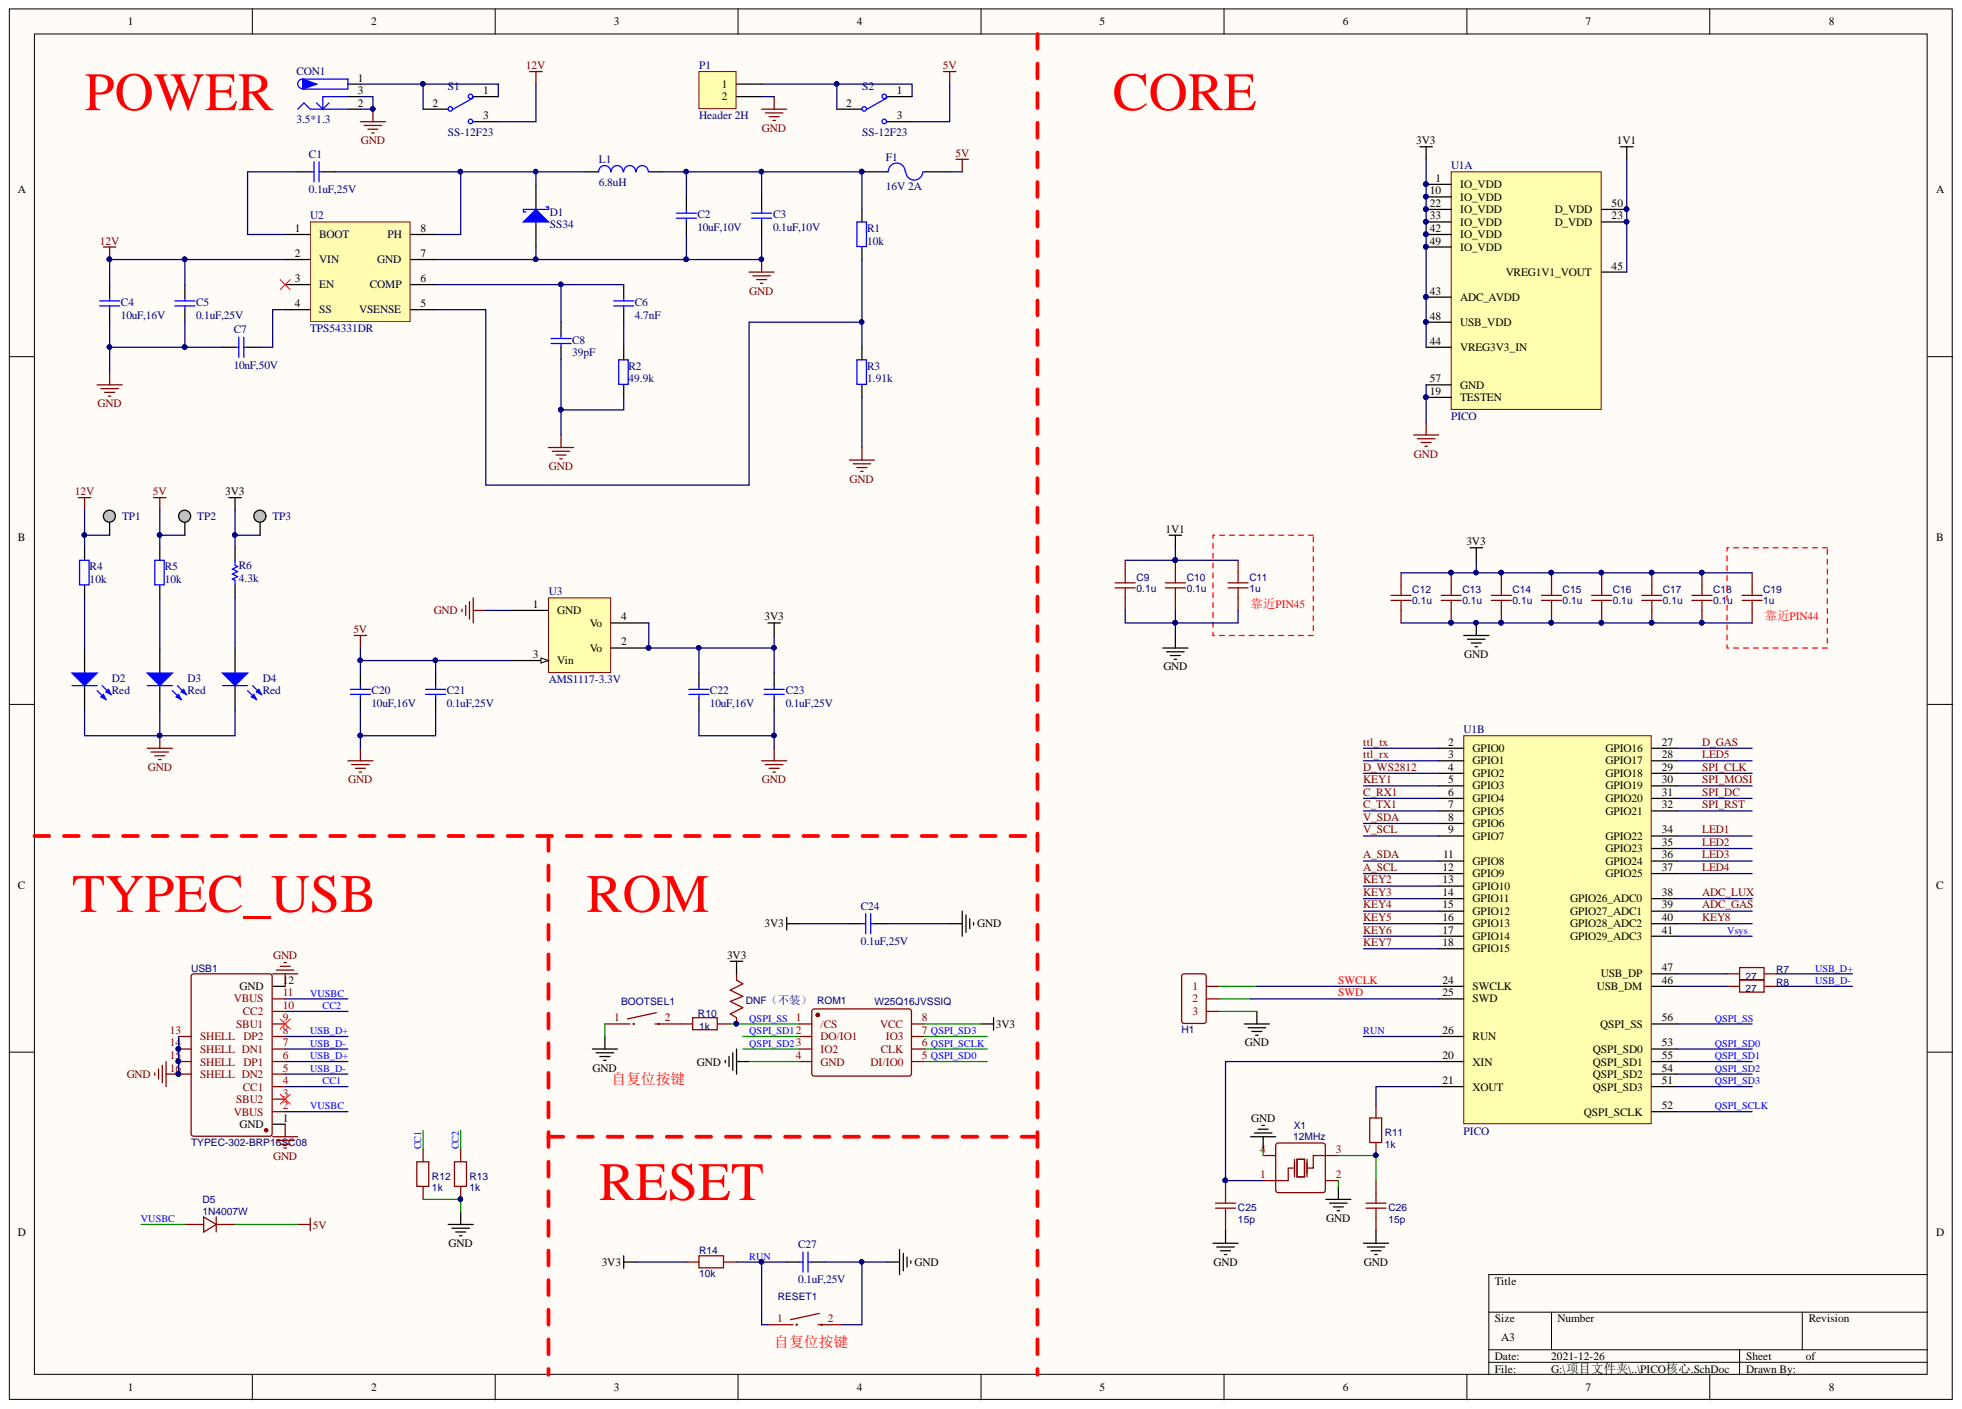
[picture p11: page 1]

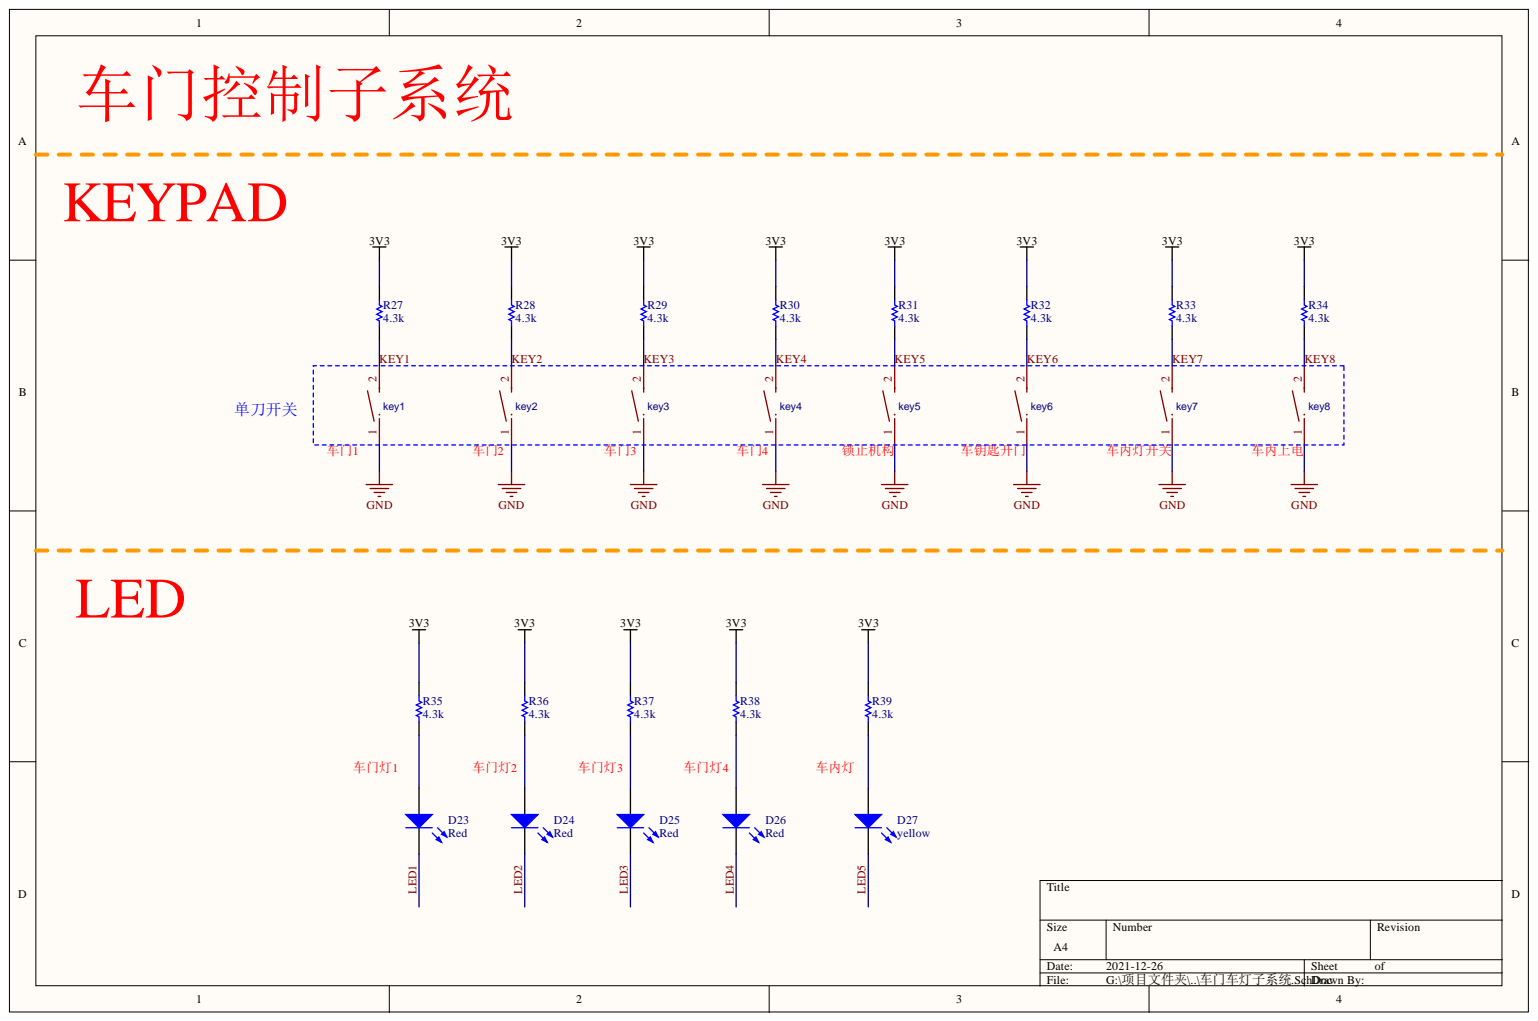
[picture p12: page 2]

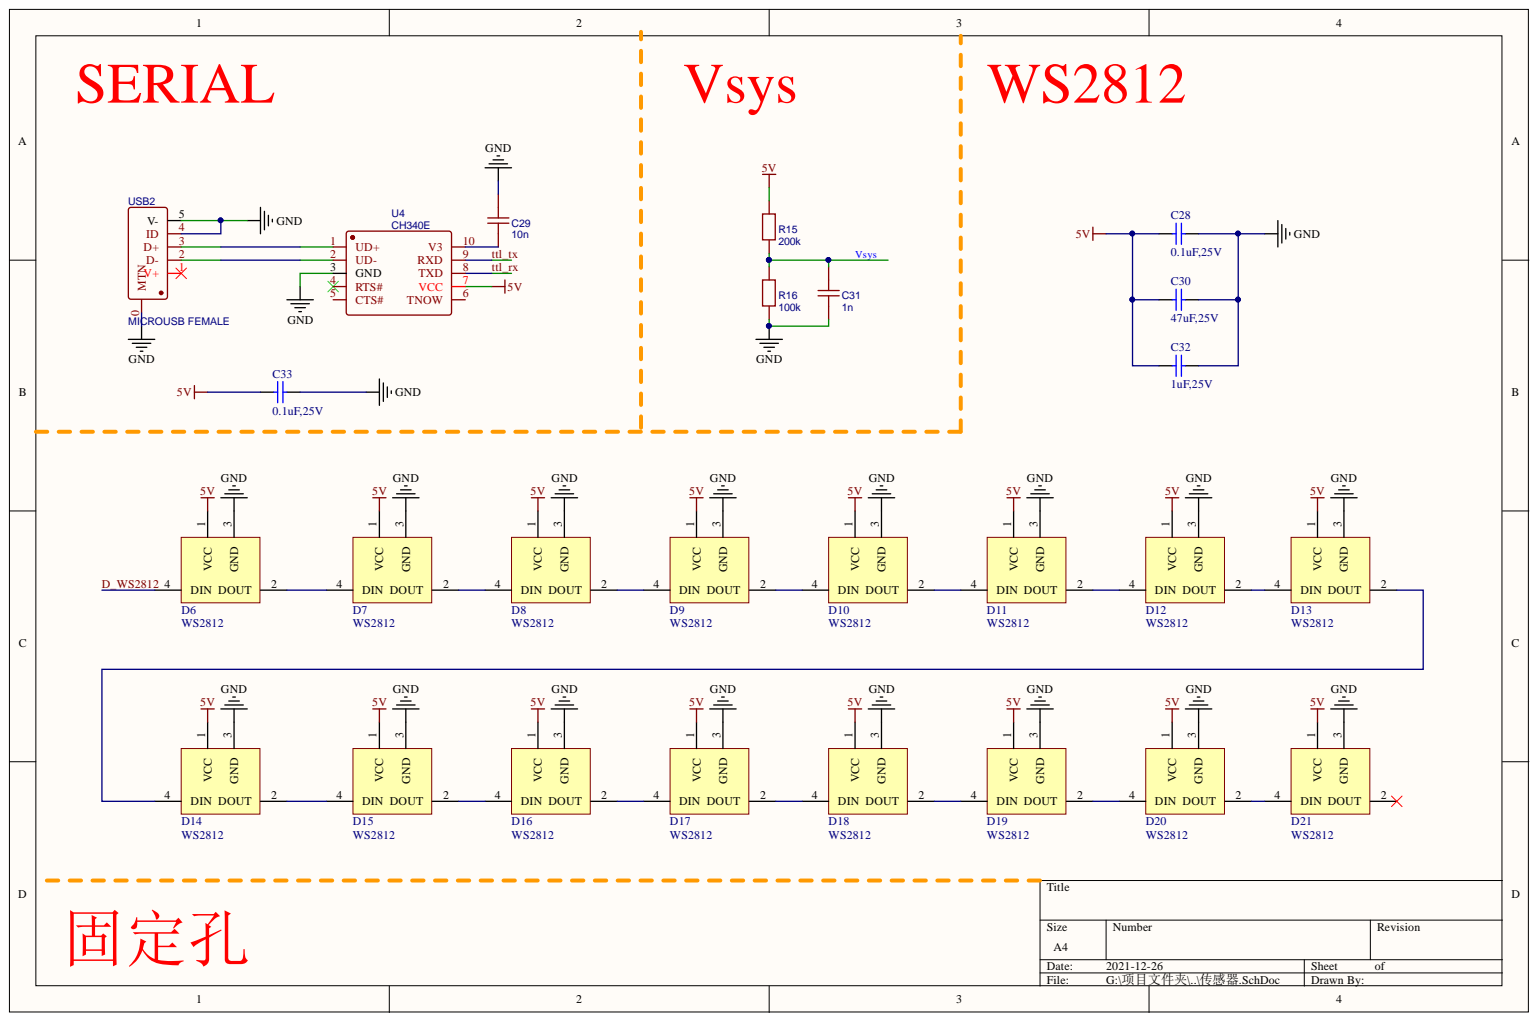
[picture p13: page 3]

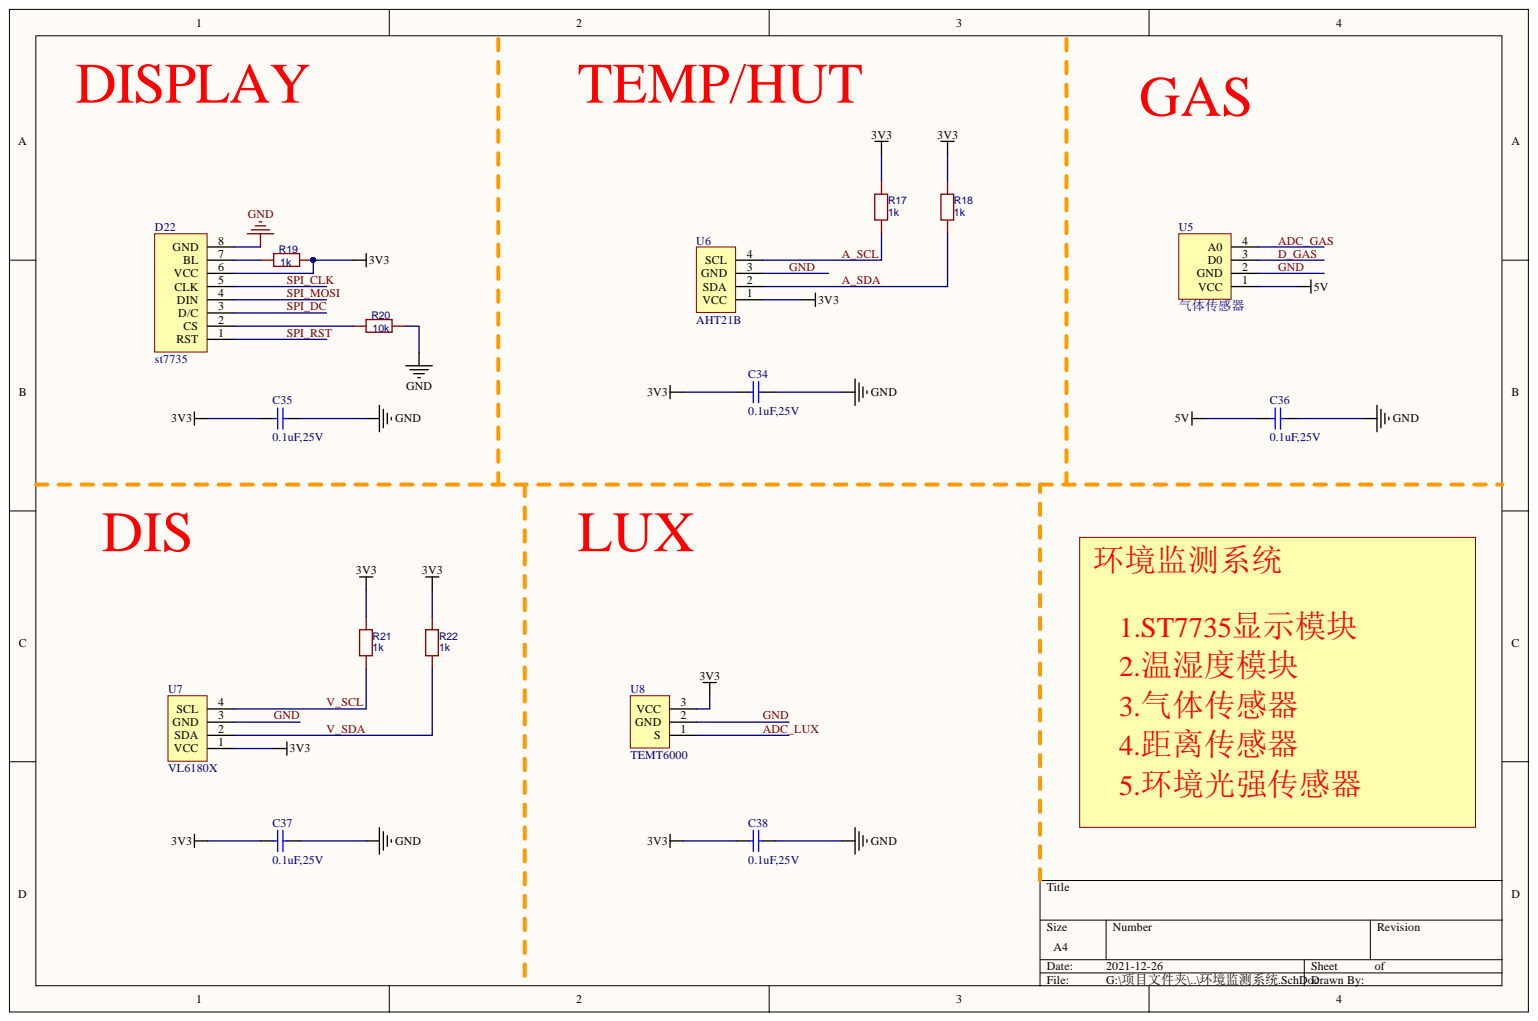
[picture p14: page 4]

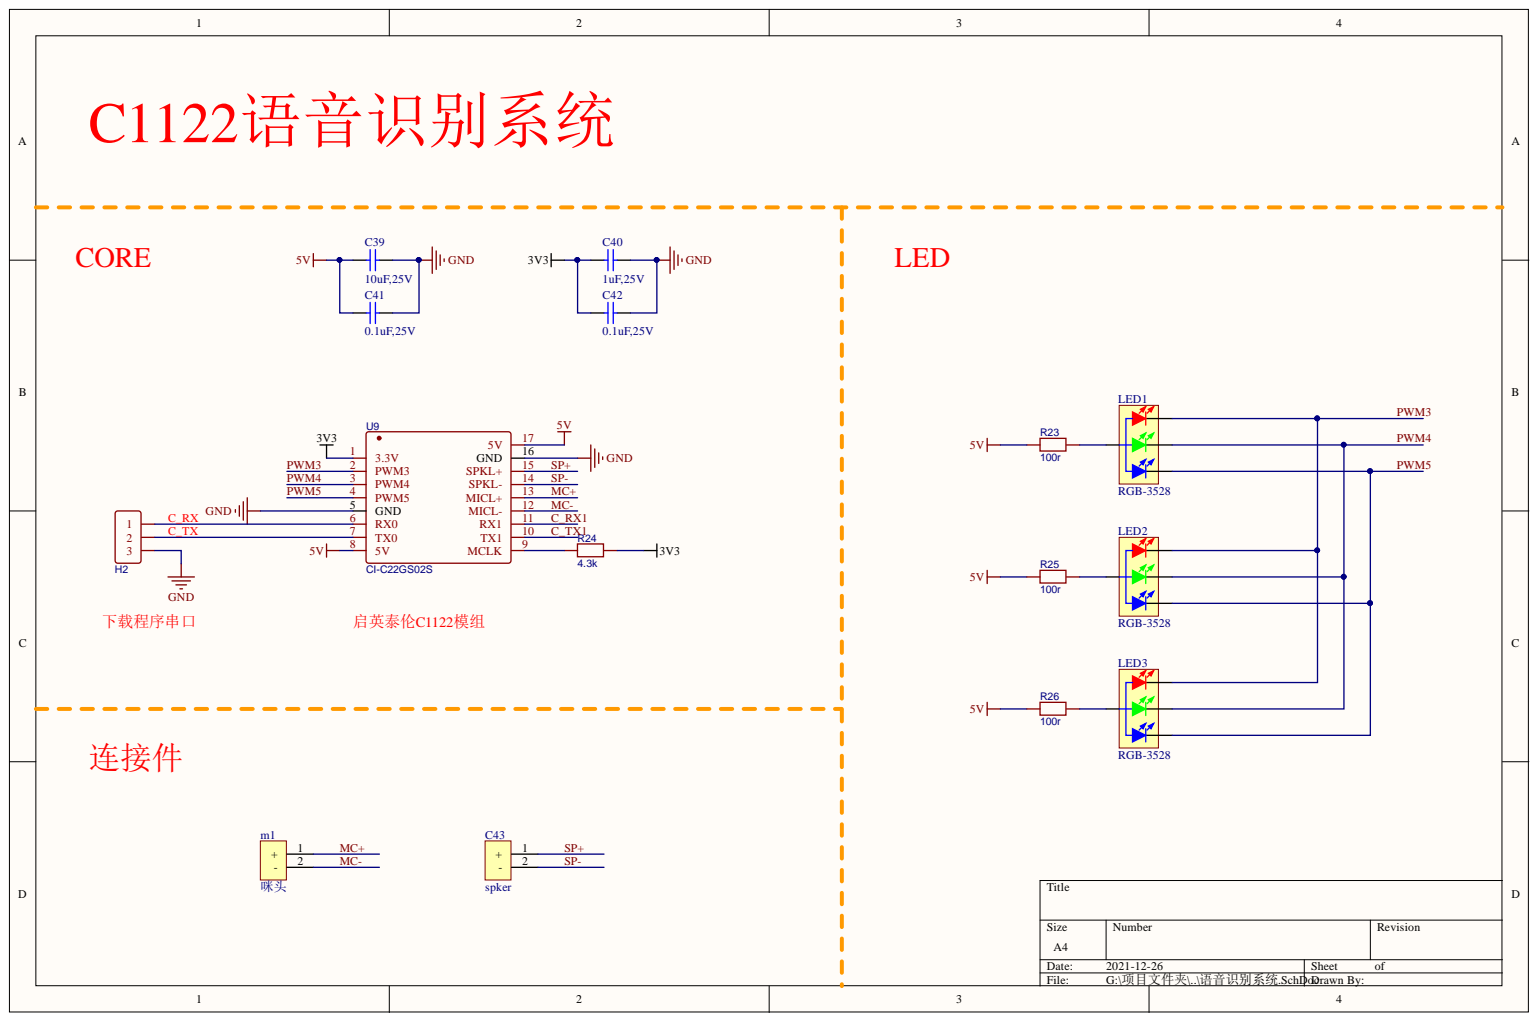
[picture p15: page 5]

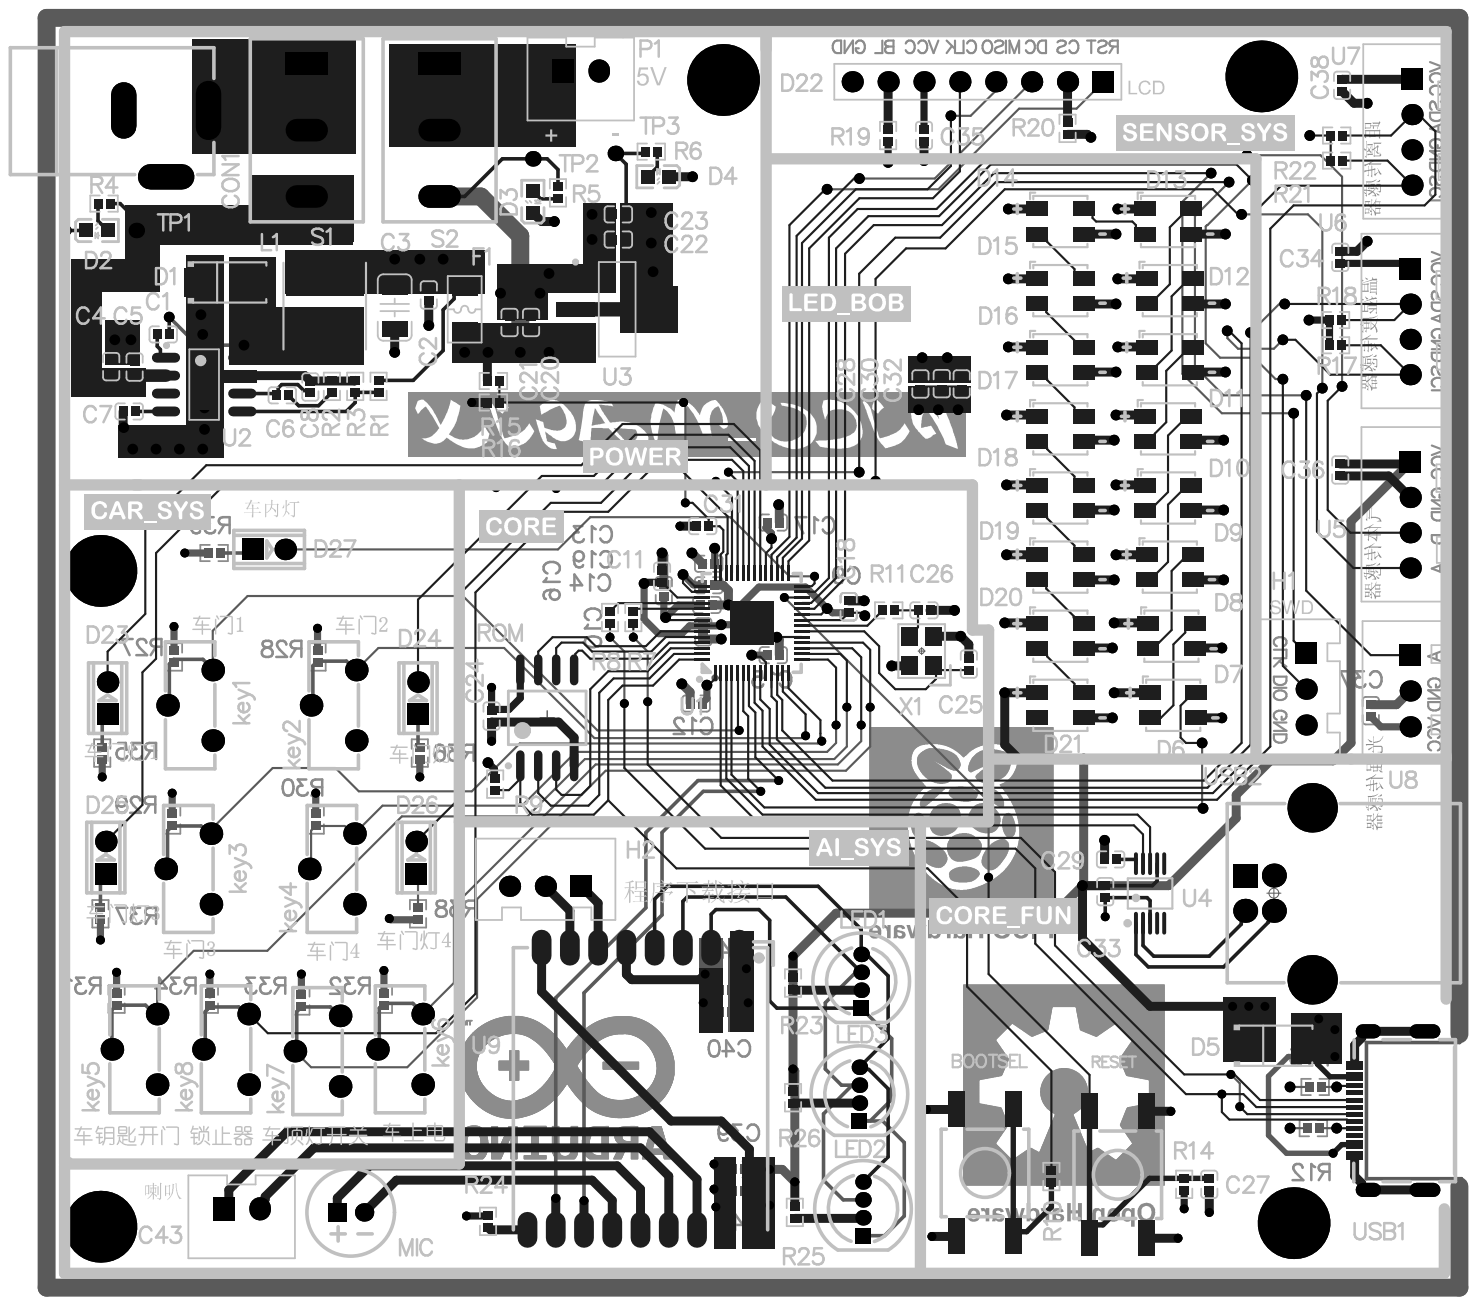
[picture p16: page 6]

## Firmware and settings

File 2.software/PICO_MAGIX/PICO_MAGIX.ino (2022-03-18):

#include "lcd.h"
#include "led.h"
#include "car_top.h"
#include "sensor.h"
#include "protocol.h"


void setup() {
  modbusSlave_Init();
  ledStrip_Init();
  ledStrip_InitProtocol();
  ledStrip_TurnAllLedOff();
  bsp_InitAllKeyPins();
  
}

void loop() {
  if(modbusSlave_poll()){
    deviceProcessCmd();
  }
  testStateMachine();
  
}

void setup1() {

  lcdInit();
  SensorSysInitAllSensor();

}

void loop1() {

  ledStrip_Run();

}

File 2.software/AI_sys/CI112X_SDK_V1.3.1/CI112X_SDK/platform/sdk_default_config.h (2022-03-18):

/**
 * @file sdk_default_config.h
 * @brief sdk配置文件
 * @version 1.0
 * @date 2019-08-08
 * 
 * @copyright Copyright (c) 2019  Chipintelli Technology Co., Ltd.
 * 
 */
#ifndef _SDK_DEFAULT_CONFIG_H_
#define _SDK_DEFAULT_CONFIG_H_

#if defined(CI_CONFIG_FILE)
#include CI_CONFIG_FILE
#endif


/******************************** sdk config *********************************/
// SDK VER
#define SDK_VERSION                    1
#define SDK_SUBVERSION                 3
#define SDK_REVISION                   1
#define SDK_TYPE                       "ASR_Offline"

// 退出唤醒时间
#ifndef EXIT_WAKEUP_TIME
#define EXIT_WAKEUP_TIME                15000   //default exit wakeup time,unit ms
#endif

// volume set
#ifndef VOLUME_MAX
#define VOLUME_MAX                      7       //voice play max volume level
#endif
#ifndef VOLUME_MID
#define VOLUME_MID                      5       //voice play middle volume level
#endif
#ifndef VOLUME_MIN
#define VOLUME_MIN                      1       //voice play min volume level
#endif

#ifndef VOLUME_DEFAULT
#define VOLUME_DEFAULT                  5       //voice play default volume level
#endif

// customer Ver (user define)
#ifndef USER_VERSION_MAIN_NO
#define USER_VERSION_MAIN_NO            1
#endif
#ifndef USER_VERSION_SUB_NO
#define USER_VERSION_SUB_NO             0
#endif
#ifndef USER_TYPE
#define USER_TYPE                       "CustomerAA"
#endif

/*for save SRAM memory used, if function define with this macro,
must be carefull,function will cover by RTOS heap,
also can used #pragma location = ".init_call"  */
//#define ININT_CALL_FUNC @ ".init_call"

#ifndef ININT_CALL_FUNC
#define ININT_CALL_FUNC
#endif

//#define ININT_CALL_DATA @ ".init_one_data"
#define ININT_CALL_DATA

/* 串口调试LOG输出 */
#ifndef CONFIG_CI_LOG_UART
#define CONFIG_CI_LOG_UART                  HAL_UART0_BASE
#endif

/* 驱动中断采用事件标准组配置为1，采用全局变量配置为0 */
#ifndef DRIVER_OS_API
#define DRIVER_OS_API                       0
#endif

#ifndef CONFIG_DIRVER_BUF_USED_FREEHEAP_EN
#define CONFIG_DIRVER_BUF_USED_FREEHEAP_EN  1
#endif

/* 在播放中是否暂停语音输入，一般来讲开启aec则不开启暂停语音输入否则开启 */
#ifndef PAUSE_VOICE_IN_WITH_PLAYING
#define PAUSE_VOICE_IN_WITH_PLAYING         1
#endif

/*是否允许关闭提示播报音 */
#ifndef PROMPT_CLOSE_EN
#define PROMPT_CLOSE_EN                     1
#endif

/*异常复位跳过上电播报 */
#ifndef EXCEPTION_RST_SKIP_BOOT_PROMPT
#define EXCEPTION_RST_SKIP_BOOT_PROMPT      1
#endif

/*默认模型分组ID，开机后第一次运行的识别环境 */
#ifndef DEFAULT_MODEL_GROUP_ID
#define DEFAULT_MODEL_GROUP_ID              0
#endif

/*VAD 指示灯开关 */
#ifndef VAD_LED_EN
#define VAD_LED_EN                          1
#if VAD_LED_EN
#define VAD_LIGHT_IO_PIN_BASE HAL_GPIO3_BASE
#define VAD_LIGHT_IO_PIN_NAME I2C0_SDA_PAD
#define VAD_LIGHT_IO_PIN_IOREUSE FIRST_FUNCTION
#define VAD_LIGHT_IO_PIN_PORT GPIO3
#define VAD_LIGHT_IO_PIN_NUMBER gpio_pin_1
#endif
#endif

/* 启用非唤醒状态切换模型 */
#ifndef USE_SEPARATE_WAKEUP_EN
#define USE_SEPARATE_WAKEUP_EN              0
#endif 

/* 启用降频模式 */
#ifndef USE_LOWPOWER_DOWN_FREQUENCY
#define USE_LOWPOWER_DOWN_FREQUENCY         0
#endif

/* 启用低功耗模式 */
#ifndef USE_LOWPOWER_OSC_FREQUENCY
#define USE_LOWPOWER_OSC_FREQUENCY          0
#endif


/* 使能IIS1相关引脚功能 */
#ifndef IIS1_ENABLE
#define IIS1_ENABLE                         1
#endif

/*************************** 语音前端算法 config *****************************/

/*单MIC DENOISE*/
#ifndef USE_SINGLE_MIC_DENOISE
#define USE_SINGLE_MIC_DENOISE             0
#endif

/*ALC AUTO SWITCH*/
#ifndef USE_ALC_AUTO_SWITCH
#define USE_ALC_AUTO_SWITCH                1
#endif


/*使用多个CODEC同时录音,需根据算法选择配合使用*/
#ifndef AUDIO_CAPTURE_USE_MULTI_CODEC
#define AUDIO_CAPTURE_USE_MULTI_CODEC      0
#endif

/*是否codec录音只支持单个声道,需根据算法选择配合使用*/
#ifndef AUDIO_CAPTURE_USE_SINGLE_CHANNEL
#define AUDIO_CAPTURE_USE_SINGLE_CHANNEL   1
#endif

/*是否有工频干扰*/
#ifndef HAS_POWER_FREQUENCY_DISTURB
#define HAS_POWER_FREQUENCY_DISTURB        1
#endif

#ifndef USE_ESTVAD
#define USE_ESTVAD                         0
#endif

/*根据codec使用的声道数来配置使用内存大小*/
#if !CONFIG_DIRVER_BUF_USED_FREEHEAP_EN
#if AUDIO_CAPTURE_USE_SINGLE_CHANNEL
    #define AUDUI_CAPTURE_NO_USE_MALLOC_BLOCK_SIZE (512U)
#else
    #define AUDUI_CAPTURE_NO_USE_MALLOC_BLOCK_SIZE (1024U)
#endif
#endif

/******************************** VP config **********************************/

//1:开启VP计算；0：关闭VP计算//目前的声纹需打开PSRAM
#ifndef USE_VP
#define USE_VP                              0
#endif

#ifndef VP_TEMPLATE_NUM
#define VP_TEMPLATE_NUM                     10
#endif

/******************************** command word self-learning config **********************************/
#ifndef USE_CWSL
#define USE_CWSL                             0 //命令词自学习(command word self-learning)
#endif

#ifndef CICWSL_TOTAL_TEMPLATE
#define CICWSL_TOTAL_TEMPLATE                5 //可存储模板数量
#endif


#if 0
#ifndef INNER_CODEC_AUDIO_IN_USE_RESAMPLE
#define INNER_CODEC_AUDIO_IN_USE_RESAMPLE   0//语音输入是否使用重采样，默认关闭（开了也没用）
#endif
#endif 

#ifndef AUDIO_CAPTURE_USE_CONST_PARA
#define AUDIO_CAPTURE_USE_CONST_PARA 1
#endif
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

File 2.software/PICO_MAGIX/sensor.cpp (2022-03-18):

#include "sensor.h"

ANALOG_SENSOR_TYPE _sensorType;
struct repeating_timer timer;
AHTxx aht20(AHTXX_ADDRESS_X38, AHT2x_SENSOR); //命名使用的AHT类


void SensorSysInitAllSensor(void){
  GasSensorInit();
  SysVoltageSensorInit();
  lightSensorInit();
  AhtSensorInit();
  vl6180x_Init();
  //启动定时器
  add_repeating_timer_ms(-100, ReadAllSensorsDate, NULL, &timer);
}



bool ReadAllSensorsDate(struct repeating_timer *t){
  static uint8_t times = 0;
  times++;
  if(times%2 == 1){
    Vl6180_Start_Range_Measurement();
  }else{
    Vl6180_Read_RangeData();
  }

  if(times >= 9){
    times = 0;
    ReadGasSensor();
    ReadVoltageSensor();
    ReadLightSensor();
    AhtTestUnit();
    Run_Vl6180_RW_RegisterMode();
  }
  // vl6180x_TestUnit();
  return true;
}

void sensor_update_Humidity(float humidity){
  uint16_t date = uint16_t(humidity * 100);
  sensor_WriteSingleHoldingRegister(SENSOR_READ_HUMIDITY,date);
}

void sensor_update_Temperture(float temperture){
  uint16_t date = uint16_t(temperture * 100);
  sensor_WriteSingleHoldingRegister(SENSOR_READ_TEMPERTURE,date);
}

void sensor_update_Distance(uint16_t distance){
  sensor_WriteSingleHoldingRegister(SENSOR_READ_DISTANCE,distance);
}


void sensor_update_SysVoltage(float voltage){
  uint16_t date = uint16_t(voltage * 1000);
  sensor_WriteSingleHoldingRegister(SENSOR_READ_SYS_VOLTAGE,date);
}

void sensor_update_gasDensity(uint16_t desity){
  sensor_WriteSingleHoldingRegister(SENSOR_READ_GAS_DENSITY,desity);
}

void sensor_update_lightIntensity(uint16_t intensity){
  sensor_WriteSingleHoldingRegister(SENSOR_READ_LIGHT_INTENSITY,intensity);
}

void sensor_WriteSingleHoldingRegister(uint16_t address,uint16_t date){
  SetSingleRegister(address,date);
}



/*************AHT21 sensor*********************/

/*******************************************
 * AHT温湿度传感器部分
 *******************************************/
float temperature = 0;
float humidity  = 0;
/*
 *函数功能：初始化AHT传感器 
 * 
 */
void AhtSensorInit(void){
  temperature = 0;
  humidity = 0;
  while (aht20.begin() != true)
  {

  }

  tft.drawString("temperature:", 0, 48, MYFONT);
  tft.fillRect(72,48,40,8,TFT_BLACK);
  tft.drawFloat(0.0, 2, 72, 48,MYFONT);
  tft.drawString("C", 110, 48, MYFONT);

  tft.drawString("humidity:", 0, 64, MYFONT);
  tft.fillRect(72,64,40,8,TFT_BLACK);
  tft.drawFloat(0.0, 2, 72, 64,MYFONT);
  tft.drawString("%RH", 110, 64, MYFONT);
}


/*
 *函数功能：测试AHT传感器函数
 * 
 */
void AhtTestUnit(void){
  
  temperature = aht20.readTemperature(); //read 6-bytes via I2C, takes 80 milliseconds
  humidity = aht20.readHumidity(AHTXX_USE_READ_DATA); //use 6-bytes from temperature reading, takes zero milliseconds!!!
  sensor_update_Humidity(humidity);
  sensor_update_Temperture(temperature);
  tft.drawString("temperature:", 0, 48, MYFONT);
  tft.fillRect(72,48,40,8,TFT_BLACK);
  tft.drawFloat(temperature, 2, 72, 48,MYFONT);
  tft.drawString("C", 110, 48, MYFONT);

  tft.drawString("humidity:", 0, 64, MYFONT);
  tft.fillRect(72,64,40,8,TFT_BLACK);
  tft.drawFloat(humidity, 2, 72, 64,MYFONT);
  tft.drawString("%RH", 110, 64, MYFONT);
}



/*******************************************
 * VL6180x距离传感器部分
 *******************************************/


void vl6180x_Init(void){
  Wire1.setSDA(PIN_ALX_SDA);
  Wire1.setSCL(PIN_ALX_SCL);
  Wire1.begin();
  VL6180x_HardInit();
}


void Vl6180_Start_Range_Measurement(void)
{
  VL6180x_StartDistanceMeasurement();
}

void Vl6180_Read_RangeData(void)
{
  uint8_t range = 0;
  range = VL6180x_Read_Distance();
  sensor_update_Distance(range);
  tft.drawString("distance:", 0, 80, MYFONT);
  tft.fillRect(72,80,40,8,TFT_BLACK);
  tft.drawNumber(range, 90, 80, MYFONT);
  tft.drawString("mm", 110, 80, MYFONT);
}

void Run_Vl6180_RW_RegisterMode(void)
{

  if(VL6180x_RW_IsReadEnable())
  {
    VL6180x_ReadAll_RW_Registers();
    dPara.coil[VL_READ_RW_ENABLE] = 0;
  }

  if(VL6180x_RW_IsWriteEnable())
  {
    VL6180x_WriteAll_RW_Registers();
    dPara.coil[VL_WRITE_RW_ENABLE] = 0;
  }

  if(VL6180x_R_IsReadResultEnable()){
    VL6180x_ReadOnly_R_Registers();
    dPara.coil[VL_READ_RESULT_ENABLE] = 0;
  }

}


bool VL6180x_RW_IsReadEnable(void)
{

    if (dPara.coil[VL_READ_RW_ENABLE])
    {
        return 1;
    }else{
        return 0;
    }
    
}


bool VL6180x_RW_IsWriteEnable(void)
{
    
    if (dPara.coil[VL_WRITE_RW_ENABLE])
    {
        return 1;
    }else{
        return 0;
    }
    
}

bool VL6180x_R_IsReadResultEnable(void)
{
    
    if (dPara.coil[VL_READ_RESULT_ENABLE])
    {
        return 1;
    }else{
        return 0;
    }
    
}


void VL6180x_ReadOnly_R_Registers(void)
{
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

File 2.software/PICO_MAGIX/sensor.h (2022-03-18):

#ifndef _SENSOR_H_
#define _SENSOR_H_

#include <Arduino.h>
#include "lcd.h"
#include "pico/stdlib.h"
#include "protocol.h"
#include <AHTxx.h>
#include <Wire.h>
#include "src/vl6180/vl6180x.h"



#define MYFONT  1 //6*6
#define FILTER_N 20
#define PIN_LIGHT_SENSOR  A0
#define PIN_GAS_SENSOR    A1
#define PIN_VSYS          A3

#define PIN_ALX_SDA       6
#define PIN_ALX_SCL       7


enum ANALOG_SENSOR_TYPE{
  T_LIGHT = 0,
  T_GAS,
  T_VSYS
};


bool ReadAllSensorsDate(struct repeating_timer *t);
void SensorSysInitAllSensor(void);

void sensor_WriteSingleHoldingRegister(uint16_t address,uint16_t date);
void sensor_update_SysVoltage(float voltage);
void sensor_update_gasDensity(uint16_t desity);
void sensor_update_lightIntensity(uint16_t intensity);
void sensor_update_Distance(uint16_t distance);
void sensor_update_Temperture(float temperture);
void sensor_update_Humidity(float humidity);


int Filter(int Pin);
int ReadAnalogSensorType(ANALOG_SENSOR_TYPE mysensor);

void AhtSensorInit(void);
void AhtTestUnit(void);

void vl6180x_Init(void);
void Run_Vl6180_RW_RegisterMode(void);
bool VL6180x_RW_IsReadEnable(void);
bool VL6180x_RW_IsWriteEnable(void);
bool VL6180x_R_IsReadResultEnable(void);
void VL6180x_WriteAll_RW_Registers(void);
void VL6180x_ReadAll_RW_Registers(void);
void VL6180x_ReadOnly_R_Registers(void);
void Vl6180_Start_Range_Measurement(void);
void Vl6180_Read_RangeData(void);


void GasSensorInit(void);
void ReadGasSensor(void);

void SysVoltageSensorInit(void);
void ReadVoltageSensor(void);

void lightSensorInit(void);
void ReadLightSensor(void);



extern ANALOG_SENSOR_TYPE _sensorType;

#endif /* _SENSOR_H_ */

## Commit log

2021-12-16 更新工程
    [PICO核心.PcbDoc, PICO核心.SchDoc, PICO核心板.PrjPcb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]
2021-12-17 添加三个子系统设计
    [PICO核心.SchDoc, PICO核心板.PrjPcb, PcbLib1.PcbLib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]
2021-12-17 原理图确定，封装待确定
    [PICO核心.PcbDoc, PICO核心.SchDoc, PICO核心板.PrjPcb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]
2021-12-18 添加数据手册
2021-12-18 更新原理图，PCB封装完成
    [PICO核心.PcbDoc, PICO核心.SchDoc, PICO核心板.PrjPcb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]
2021-12-18 更新PCB
    [PICO核心.PcbDoc]
2021-12-19 创建PICO软件
2021-12-19 完成第一版原理图、PCB
    [PICO核心.PcbDoc, PICO核心板.PrjPcb]
2021-12-20 增加板子的生产文件
    [PICO核心.PcbDoc, PICO核心板.PrjPcb, PcbLib1.PcbLib]
2021-12-20 增加LCD的ST7735驱动文件
2021-12-20 新增代码文档部分
2021-12-21 更新了错误的网络标号。
    这次更新将PCB的网络标号更新了。软件部分编写了几个使用的库文件。
    [PICO核心.PcbDoc, PICO核心.SchDoc, PICO核心板.PrjPcb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]
2021-12-21 添加MQ135等传感器驱动
2021-12-23 找到了使用IDE来下载程序的方法
2021-12-26 导出BOM,原理图PDF
    购买了原件
    [PICO核心板.PrjPcb, PICO核心板.xls, 语音识别系统.SchDoc]
2022-01-04 更新了语音模块和WS2812模块
    [PICO核心板.PrjPcb, [60000]{cmd_info}.xls, 命令词列表_中文模板.xlsx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]
2022-01-13 修改文档结构
2022-03-05 更新modbus协议
    [Modbus协议栈综合实例参数地址分配表.xlsx]
2022-03-05 更新驱动程序
2022-03-06 更新通信协议
2022-03-06 删除使用arduino modbus库文件
2022-03-07 添加通信协议，初步的modbus协议继续完善。
2022-03-18 完善软件工程
    [[60000]{cmd_info}.xls, {cmd_info} - 副本.xls]
